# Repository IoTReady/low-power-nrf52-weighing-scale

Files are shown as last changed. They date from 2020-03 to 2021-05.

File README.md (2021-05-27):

# Smart Weighing Scale  

This project describes a Smart Weighing Scale with low current consumption, and hence a long battery backup.

One of the biggest problems with the use of weighing scales in flexible retail or industrial applications is the need to provide a source of power to a scale. This causes problems such as safety hazards with a corded scale, inflexibility of placement since the location of power sources limits where the scale can be placed, and finally the inability to function when there is a power interruption. This design eliminates these disadvanteges.

## Firmware
After cloning or downloading this repo find the firmware documentation here "weighing_scale_nrf/firmware/bootloader/documentation/index.html".

## Circuit

### Power Supply
The nrf Based Weighing Scale operates on 3.3V, and is powered by a 3.7V Li-ion battery.
We use a p-MOSFET(IRLML6401) for reverse polarity protection, and a LDO(Low Drop Out) Regulator(TPS7A0233PDBV) to get a stable 3.3V output supply.

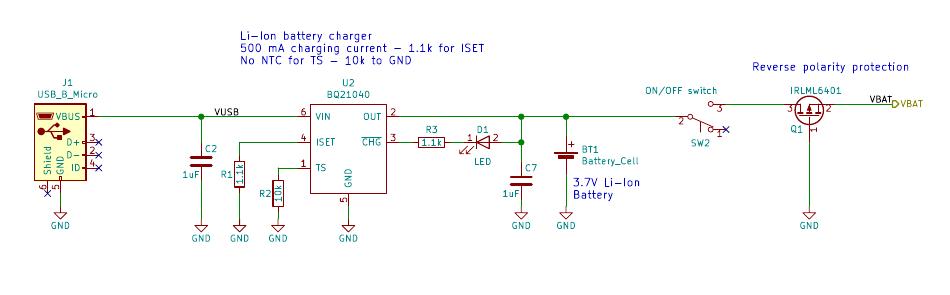
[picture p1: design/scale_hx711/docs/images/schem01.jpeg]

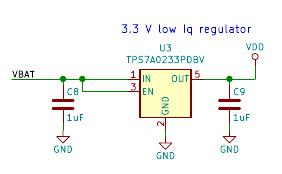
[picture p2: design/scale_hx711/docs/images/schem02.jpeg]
battery


### Battery Charging
We use a Li-ion/Li-polymer linear battery charger IC(BQ21040) for charging the battery via a micro-USB outlet. The led indicator stops glowing when the battery is fully charged.

### nRF Module
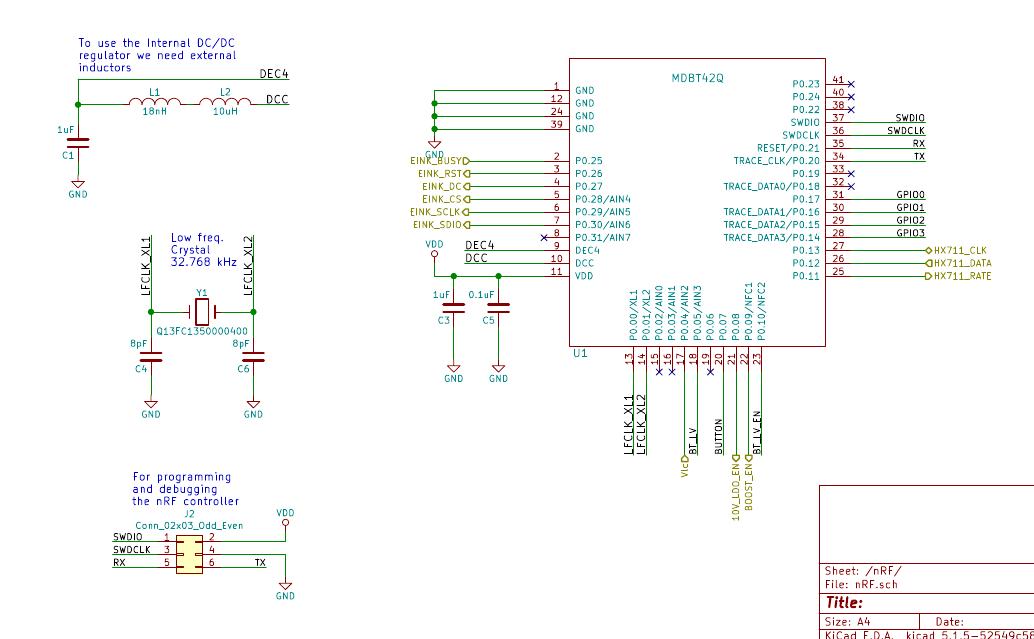
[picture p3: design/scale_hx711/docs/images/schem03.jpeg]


We are using the MDBT42Q nRF52840 based module as our main MCU and BLE module. It is a very low current consuming and high performance module.
It needs a 3.3V power supply, and we are using its internal DC/DC regulator which is set by connecting a 10uH and 18nH inductor at DCC and DEC4 pins as shown here. We also use an external 32.768 kHz external crystal. For programming this module we need a Segger JLink Debugger, which is available as a separate device or one could use an on-board debugger from any of the Nordic Dev-boards like PCA400, etc...
We kept a few GPIOs out for future use or if need to integrate anything else with the weighing scale.

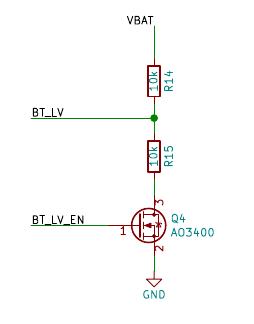
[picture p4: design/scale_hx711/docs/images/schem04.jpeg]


To measure the battery level we use this voltage divider circuit and measure it use the on board ADC pins.

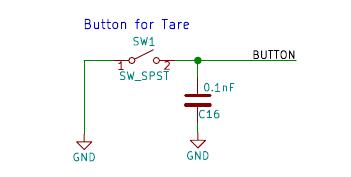
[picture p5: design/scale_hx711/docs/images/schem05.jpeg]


Tare Button is a push button for using the tare functionality. It basically resets the displayed weight on scale back to zero. The Tare button can also be used to measure multiple items in the same container. Simply add you first item, note the weight, press Tare and you are ready to weigh your next item.

### ADC Circuit: HX711
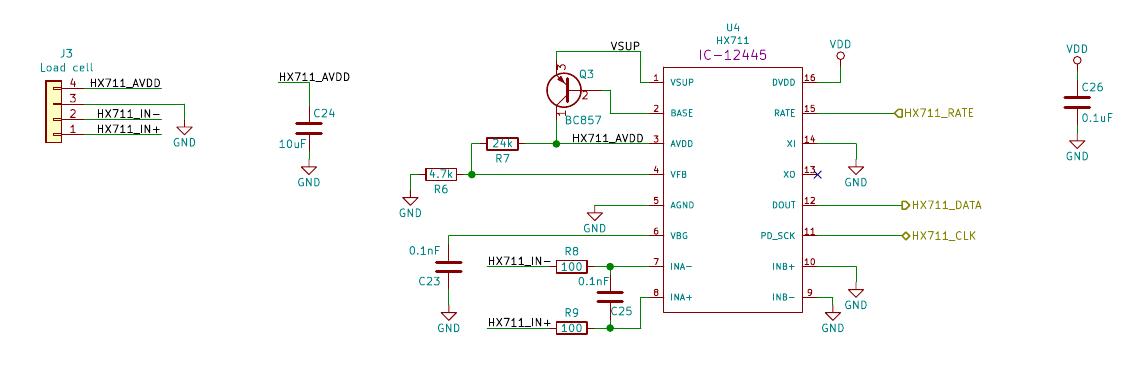
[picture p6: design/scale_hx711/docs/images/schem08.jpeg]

For measuring the weighing scale we use a Load Cell which gives an anlog output, as the weight changes. For high accuracy we use HX711 24-bit ADC chip, which is designed specifically for industrial weighing scales and other industrial control applications.

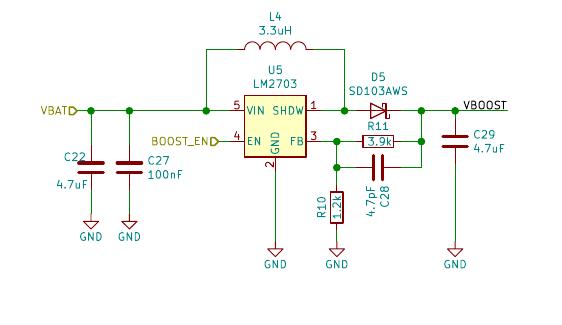
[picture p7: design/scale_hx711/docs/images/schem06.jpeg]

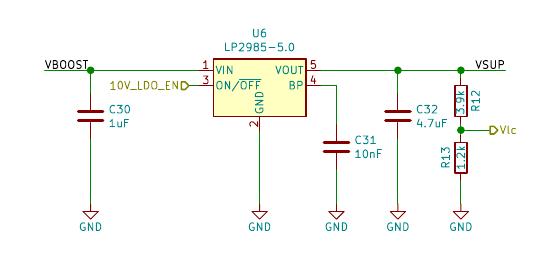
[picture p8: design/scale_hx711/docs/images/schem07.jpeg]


To power the HX711 we need a 5V supply, so we use a Boost regulator(LM2703) to step-up the 3.7V from the battery supply and use an LDO(LP2985-5.0) to get a stable noise free 5V supply for HX711.

The data from the Load Cell is received via four pins HX711_IN+, HX711_IN-, HX711_AVDD and GND. This data is processed by the ADC chip and an output is send via serial interface to the nRF module. We can control the output data rate as either 10Hz or 80Hz by controlling the HX711_RATE pin state.
There is no programming needed for the internal registers. All controls to the HX711 are through the pins.

### E-Ink Display
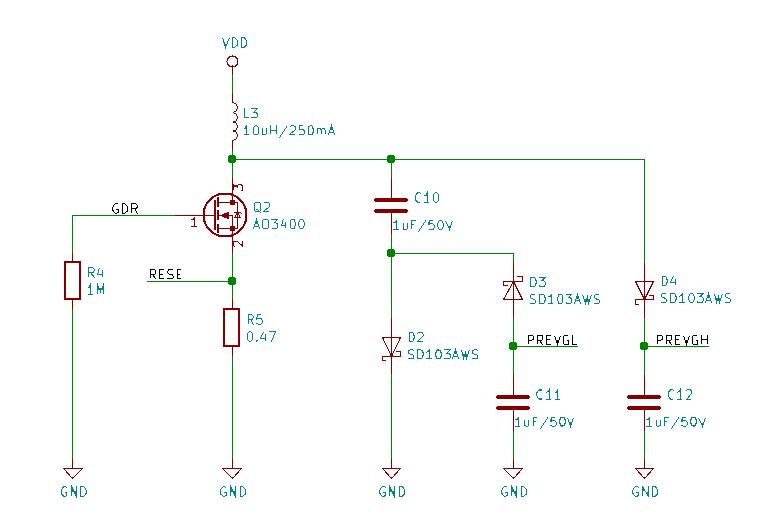
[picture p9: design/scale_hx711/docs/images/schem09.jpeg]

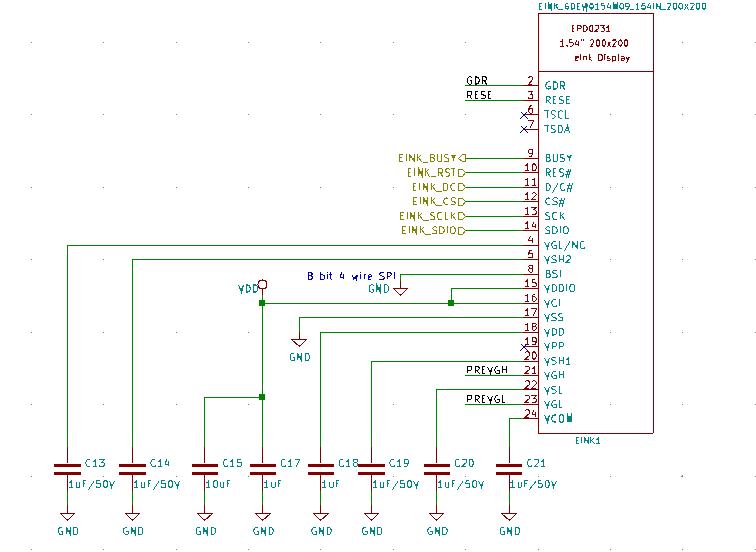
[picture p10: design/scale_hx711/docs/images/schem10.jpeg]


We decided to go with an E-Ink display as it is very low power consuming, reflection resistant, and was useful for the application we were targeting.
This is a 1.54" 200x200 pixel [E-Ink display](https://www.e-paper-display.com/products_detail/productId=513.html) from Good Display.

## PCB
This is what the final PCB design looks like:
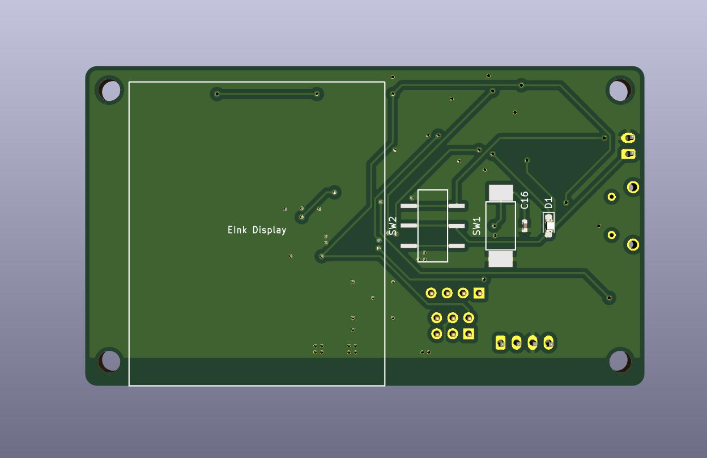
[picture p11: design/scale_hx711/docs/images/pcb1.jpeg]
front_pcb

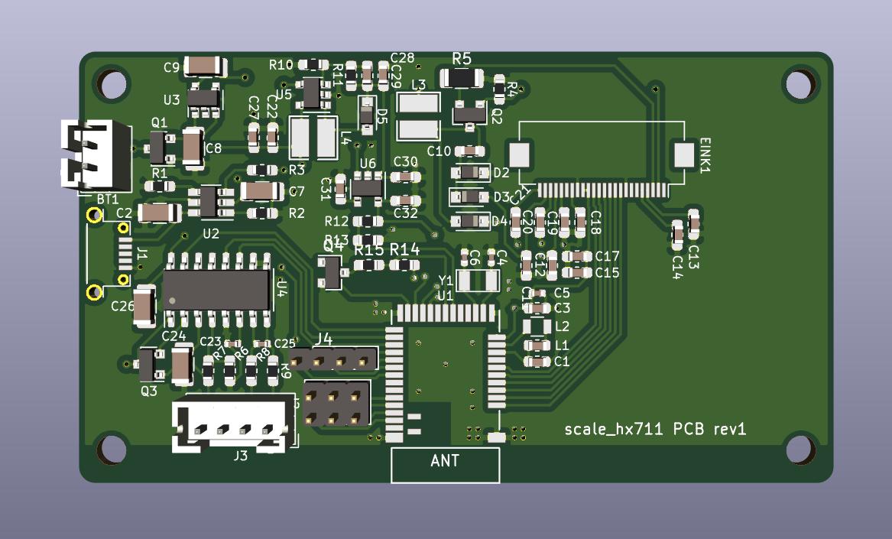
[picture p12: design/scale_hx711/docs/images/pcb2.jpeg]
back_pcb

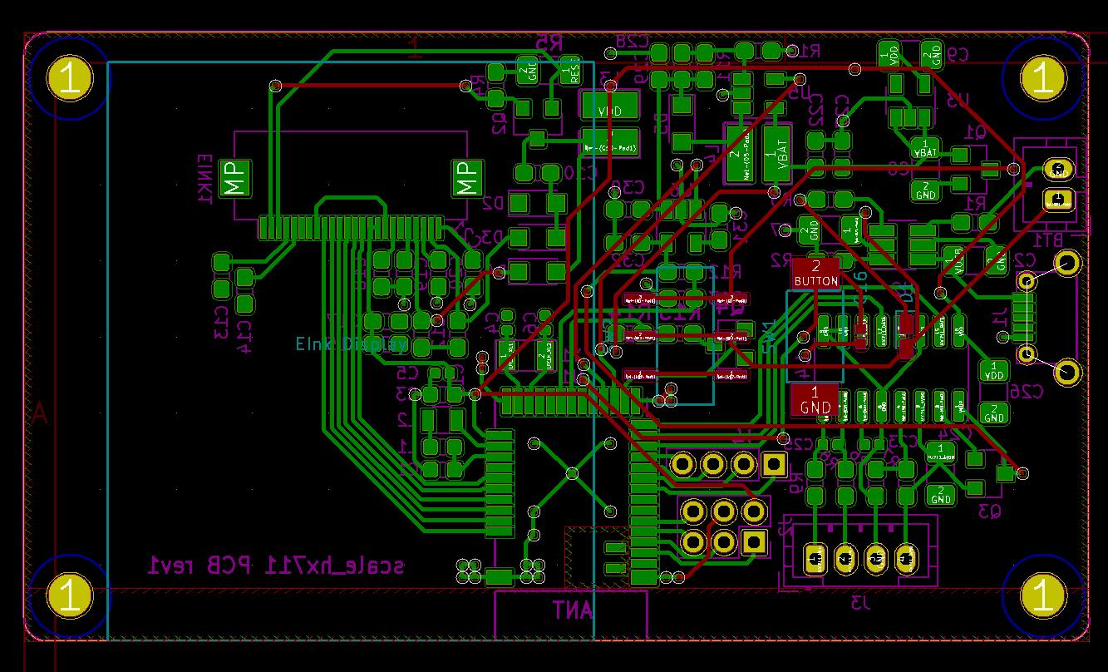
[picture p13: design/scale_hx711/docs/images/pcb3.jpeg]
gerber_pcb


## Hardware Builds

Hardware design files are available in the "design" sub-folder

We tried 3 different designs for the weighing scale project and settled with the "HX711" based design as our final.

So you will find the final design explained on the main page.

The other two designs of "LPV821" and "LTC6915" based weighing scales are also fully functional, one may have to play around with the adc functions in the firmware though.

## Software Builds

One can find the main application with all library files(for e-ink display, and weighing scale) in the "Application" folder.

To setup the Nordic SDK and bootloader files follow the links in "Bootloader" folder. Also, the "documentation" folder has some good technical data.

To make changes in the firmware go to "weighing_scale_nrf/firmware/application/w_scale_all/" and make necessary changes.

To build the output files, go to the same location and use this command to generate final output files(.hex):
```
make release
```

Then use the following to flash and debug the firmware:
```
make upload
```

This is a custom makefile, so make sure all Debugger setings are proper. Like, make sure the Debugge name and Serial Number are correct.

These can be set in this [makefile](https://github.com/IoTReady/weighing_scale_nrf/blob/master/firmware/application/w_scale_all/Makefile).

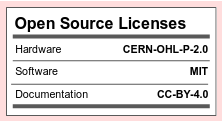
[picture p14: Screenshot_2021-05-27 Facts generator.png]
opensource license


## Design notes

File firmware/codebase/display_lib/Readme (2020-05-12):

This driver gives an abstraction layer for multiple e-paper displays. But,
functionalities provided by this driver will be limited to print text, and 
rectangles.

1. Number of lines calculations. 
Number of pixels per line = (Height of selected font +
                                    Before each line 4 empty pixels)

Max number of lines = (total pixels / no of pixels per line)

2. Number of characters in line = (total pixel / Width of selected font).

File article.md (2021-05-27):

# Building a low power, smart weighing scale

### How did we get into this?

Online grocery shopping is booming. We were approached by a new startup to help them build a tracking infrastructure. A key componet of this infrastructre was a weighing station that could be combined with a bar-code printer and a reader to automatically identify, weigh and update information on Stock Keeping Units (SKU's) as they flowed through the grocery processing flow.

Conventional scales have been manufactured for a long time. Its also possible to fairly easily integrate them with scanners and printers. However in this case more was needed:
 
* Identify everything that's weighed on them and be able to update information on the item
* Integrate the item information into the startups workflow management system
* Enable the placement of these devices where needed by the layout of processing stations, and the ability to move them around as required
* Ensure that these devices were capable of handling power interruptions

Keeping all these features in mind we came up with two variants: Weighing Scales with WiFi or BLE.
After further research, development, feild testing and lots of discussions we decided to go ahead with the BLE alternative. It is much more power efficient, cheaper and met all the requirements we were looking for.

### Hardware design and development

For low power, Bluetooth Low Energy (BLE), there is no better option in the market other than Nordic Semiconductor's nRF series. So, based on requirements, availability and price we went with nRF52840 based module "MDBT42Q". One can find all the design files and a more technical documentation in our GitHub repo [here](https://github.com/IoTReady/weighing_scale_nrf).

Basically a weighing scale has a load cell which helps determine the weight of an object put on it. The load-cell signal uses an op-amp circuit to get a improve the signal and an ADC (Analog-to-Digital Converter) to calculate the final weight of the object. We used the ADC on the nRF52840 chip and for the Amplifier circuit we tried three different options:

* LPV821
* LTC6915
* HX711

After further testing and comparison of all three we decided to go with "HX711" circuit. It gave us the most stable results and power consumption was also the least expensive compared to the rest. We are sharing all three designs in our open-source repo, but we only provide more technical data on HX711 circuit for now.

The next requirement was for a display showing weight, battery life and charging status of the device. To keep it low power we tried out E-Ink displays. They met all our expectations on how much less current they draw compared to conventional LED displays. We settled on a 1.54 inch 200x200 pixel [E-Ink Display](https://www.e-paper-display.com/products_detail/productId=513.html) from Good Display.

Here is some data on the power consumption of the device:

Powering the device is simple. Users can install any 3.7V Li-Ion battery, as per their requirement. It can be charged via the micro-USB port on the device.

Finally, we have a Tare Button. It is a push button user can press to define their own zero reference and measure anything with respect to that.

### Connecting to the Internet

As we decided to go with BLE, there was no way for the device to directly connect to the internet. Hence, we developed a small mobile App which functions as a background gateway between the weighing scale and the factory intranet. A user will link to the device with the mobile App once. The device will keep sending all the weight data measured on it over BLE in addition to recording it, which will then be sent to the internet(company database or inventory tracking application) from the smart phone.

This way we record all the data with minimal power consumption by the device.

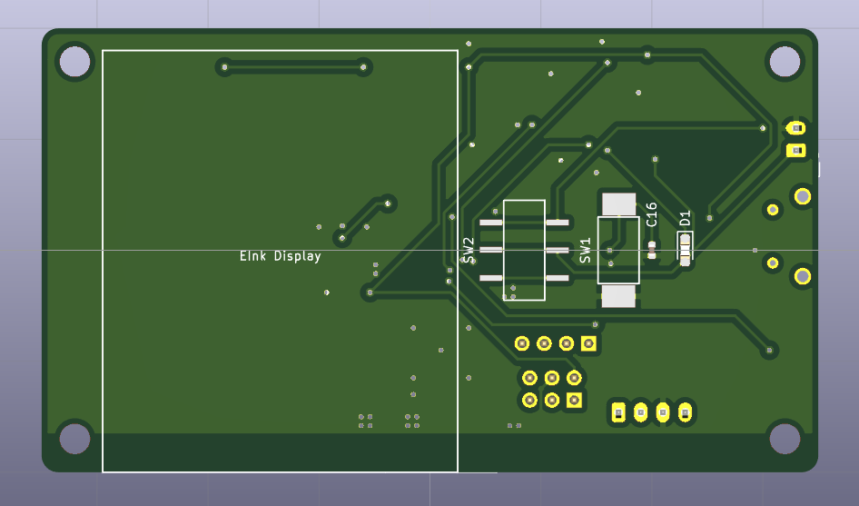
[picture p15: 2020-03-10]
design/scale_hx711/docs/scale_hx711_pcb_1.png

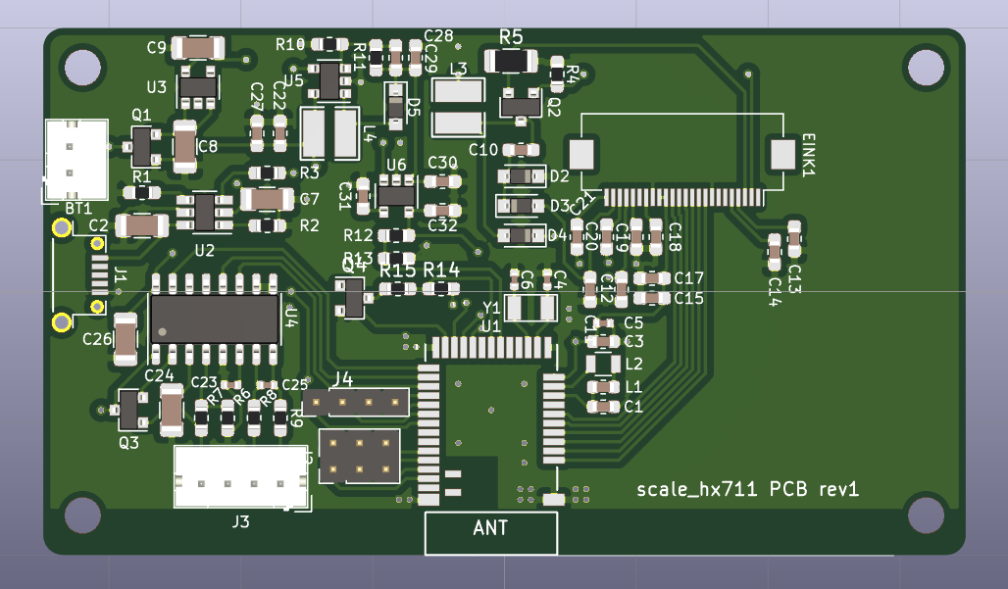
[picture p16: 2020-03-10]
design/scale_hx711/docs/scale_hx711_pcb_2.png

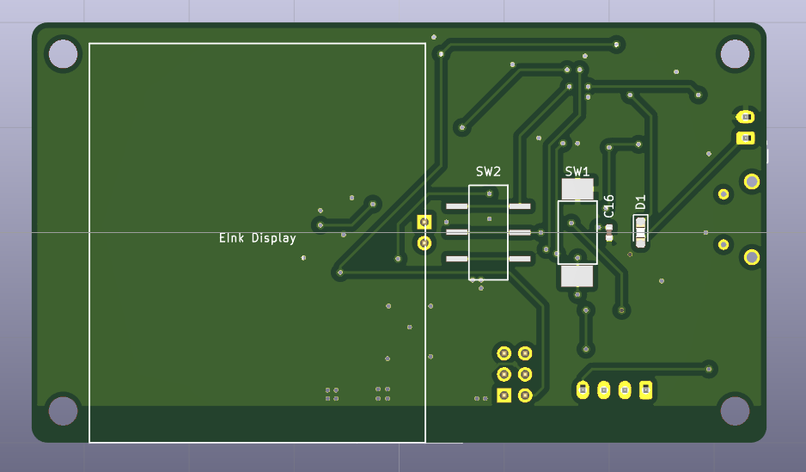
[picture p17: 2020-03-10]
design/scale_ltc6915/docs/scale_ltc6915_pcb_1.png

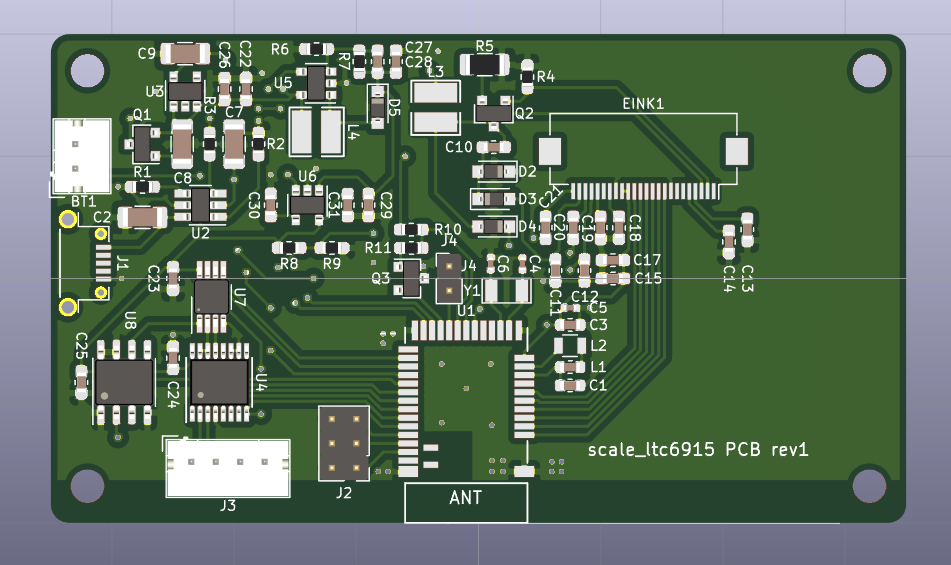
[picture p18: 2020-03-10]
design/scale_ltc6915/docs/scale_ltc6915_pcb_2.png

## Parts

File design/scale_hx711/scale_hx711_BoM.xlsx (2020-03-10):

Source: | /home/shubham/IoTReady/nrf_scale/weighing_scale_nrf/design/scale_hx711/scale_hx711.sch
Date: | Tue Mar 10 15:40:08 2020
Tool: | Eeschema 5.1.5-52549c5~84~ubuntu18.04.1
Component Count: | 79
Ref | Value | Footprint | Datasheet | Manufacturer | Vendor
BT1 | Battery_Cell | Connector_JST:JST_PH_B2B-PH-K_1x02_P2.00mm_Vertical
C1 | 1uF | sense_fp:C_0603_1608Metric
C2 | 1uF | sense_fp:C_1206_3216Metric
C3 | 1uF | sense_fp:C_0603_1608Metric
C4 | 8pF | sense_fp:C_0402_1005Metric
C5 | 0.1uF | sense_fp:C_0402_1005Metric
C6 | 8pF | sense_fp:C_0402_1005Metric
C7 | 1uF | sense_fp:C_1206_3216Metric
C8 | 1uF | sense_fp:C_1206_3216Metric
C9 | 1uF | sense_fp:C_1206_3216Metric
C10 | 1uF/50V | Capacitor_SMD:C_0603_1608Metric_Pad1.05x0.95mm_HandSolder
C11 | 1uF/50V | Capacitor_SMD:C_0603_1608Metric_Pad1.05x0.95mm_HandSolder
C12 | 1uF/50V | Capacitor_SMD:C_0603_1608Metric_Pad1.05x0.95mm_HandSolder
C13 | 1uF/50V | Capacitor_SMD:C_0603_1608Metric_Pad1.05x0.95mm_HandSolder
C14 | 1uF/50V | Capacitor_SMD:C_0603_1608Metric_Pad1.05x0.95mm_HandSolder
C15 | 10uF | Capacitor_SMD:C_0603_1608Metric_Pad1.05x0.95mm_HandSolder
C16 | 0.1nF | sense_fp:C_0402_1005Metric
C17 | 1uF | Capacitor_SMD:C_0603_1608Metric_Pad1.05x0.95mm_HandSolder
C18 | 1uF | Capacitor_SMD:C_0603_1608Metric_Pad1.05x0.95mm_HandSolder
C19 | 1uF/50V | Capacitor_SMD:C_0603_1608Metric_Pad1.05x0.95mm_HandSolder
C20 | 1uF/50V | Capacitor_SMD:C_0603_1608Metric_Pad1.05x0.95mm_HandSolder
C21 | 1uF/50V | Capacitor_SMD:C_0603_1608Metric_Pad1.05x0.95mm_HandSolder
C22 | 4.7uF | Capacitor_SMD:C_0603_1608Metric_Pad1.05x0.95mm_HandSolder | ~
C23 | 0.1nF | sense_fp:C_0402_1005Metric
C24 | 10uF | sense_fp:C_1206_3216Metric
C25 | 0.1nF | sense_fp:C_0402_1005Metric
C26 | 0.1uF | sense_fp:C_1206_3216Metric
C27 | 100nF | Capacitor_SMD:C_0603_1608Metric_Pad1.05x0.95mm_HandSolder | ~
C28 | 4.7pF | Capacitor_SMD:C_0603_1608Metric_Pad1.05x0.95mm_HandSolder | ~
C29 | 4.7uF | Capacitor_SMD:C_0603_1608Metric_Pad1.05x0.95mm_HandSolder | ~
C30 | 1uF | Capacitor_SMD:C_0603_1608Metric_Pad1.05x0.95mm_HandSolder | ~
C31 | 10nF | Capacitor_SMD:C_0603_1608Metric_Pad1.05x0.95mm_HandSolder | ~
C32 | 4.7uF | Capacitor_SMD:C_0603_1608Metric_Pad1.05x0.95mm_HandSolder | ~
D1 | LED | LED_SMD:LED_0603_1608Metric_Castellated
D2 | SD103AWS | Diode_SMD:D_SOD-323_HandSoldering | ~
D3 | SD103AWS | Diode_SMD:D_SOD-323_HandSoldering | ~
D4 | SD103AWS | Diode_SMD:D_SOD-323_HandSoldering | ~
D5 | SD103AWS | Diode_SMD:D_SOD-323_HandSoldering | ~
EINK1 | EINK_GDEW0154M09_154IN_200X200 | Connector_FFC-FPC:Hirose_FH12-24S-0.5SH_1x24-1MP_P0.50mm_Horizontal
J1 | USB_B_Micro | Footprint_nrf_scale:Micro_usb_connector_4_THT_pads | ~
J2 | Conn_02x03_Odd_Even | Connector_PinHeader_2.00mm:PinHeader_2x03_P2.00mm_Vertical | ~
J3 | Load cell | Connector_JST:JST_PH_B4B-PH-K_1x04_P2.00mm_Vertical
J4 | Conn_01x04 | Connector_PinHeader_2.00mm:PinHeader_1x04_P2.00mm_Vertical | ~
L1 | 18nH | sense_fp:C_0603_1608Metric
L2 | 10uH | sense_fp:L_0805
L3 | 10uH/250mA | Footprint_nrf_scale:L_3.5x3.0mm_CD30D22
L4 | 3.3uH | Footprint_nrf_scale:L_3.5x3.0mm_CD30D22
MK1 | Mounting_Hole | sense_fp:MountingHole_2.7mm_M2.5
MK2 | Mounting_Hole | sense_fp:MountingHole_2.7mm_M2.5
MK3 | Mounting_Hole | sense_fp:MountingHole_2.7mm_M2.5
MK4 | Mounting_Hole | sense_fp:MountingHole_2.7mm_M2.5
Q1 | IRLML6401 | Package_TO_SOT_SMD:SOT-23
Q2 | AO3400 | Package_TO_SOT_SMD:SOT-23
Q3 | BC857 | Package_TO_SOT_SMD:SOT-23 | http://www.fairchildsemi.com/ds/BC/BC557.pdf
Q4 | AO3400 | Package_TO_SOT_SMD:SOT-23
R1 | 1.1k | Resistor_SMD:R_0603_1608Metric_Pad1.05x0.95mm_HandSolder
R2 | 10k | Resistor_SMD:R_0603_1608Metric_Pad1.05x0.95mm_HandSolder
R3 | 1.1k | Resistor_SMD:R_0603_1608Metric_Pad1.05x0.95mm_HandSolder
R4 | 1M | Resistor_SMD:R_0603_1608Metric_Pad1.05x0.95mm_HandSolder
R5 | 0.47 | Resistor_SMD:R_1206_3216Metric
R6 | 4.7k | Resistor_SMD:R_0603_1608Metric_Pad1.05x0.95mm_HandSolder
R7 | 24k | Resistor_SMD:R_0603_1608Metric_Pad1.05x0.95mm_HandSolder
R8 | 100 | Resistor_SMD:R_0603_1608Metric_Pad1.05x0.95mm_HandSolder
R9 | 100 | Resistor_SMD:R_0603_1608Metric_Pad1.05x0.95mm_HandSolder
R10 | 1.2k | Resistor_SMD:R_0603_1608Metric_Pad1.05x0.95mm_HandSolder
R11 | 3.9k | Resistor_SMD:R_0603_1608Metric_Pad1.05x0.95mm_HandSolder
R12 | 3.9k | Resistor_SMD:R_0603_1608Metric_Pad1.05x0.95mm_HandSolder
R13 | 1.2k | Resistor_SMD:R_0603_1608Metric_Pad1.05x0.95mm_HandSolder
R14 | 10k | Resistor_SMD:R_0603_1608Metric_Pad1.05x0.95mm_HandSolder
R15 | 10k | Resistor_SMD:R_0603_1608Metric_Pad1.05x0.95mm_HandSolder
SW1 | SW_SPST | Footprint_nrf_scale:SMD Tactile Switch_3x6x2.5mm
SW2 | ON/OFF switch | Footprint_nrf_scale:Slide Switch SMD 2P2T _6pins
U1 | MDBT42Q | sense_fp:mdbt42Q
U2 | BQ21040 | Package_TO_SOT_SMD:SOT-23-6_Handsoldering | http://www.ti.com/lit/ds/symlink/bq21040.pdf
U3 | TPS7A0233PDBV | Package_TO_SOT_SMD:SOT-23-5 | http://www.ti.com/lit/ds/symlink/tps7a02.pdf
U4 | HX711 | Package_SO:SOIC-16_3.9x9.9mm_P1.27mm
U5 | LM2703 | Package_TO_SOT_SMD:SOT-23-5
U6 | LP2985-5.0 | Package_TO_SOT_SMD:SOT-23-5 | http://www.ti.com/lit/ds/symlink/lp2985.pdf
Y1 | Q13FC1350000400 | sense_fp:Q13FC1350000400_SMD Crystals 32.768KHz

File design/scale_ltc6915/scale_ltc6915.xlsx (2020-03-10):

Source: | /home/shubham/IoTReady/nrf_scale/weighing_scale_nrf/design/scale_ltc6915/scale_ltc6915.sch
Date: | Tue Mar 10 15:40:26 2020
Tool: | Eeschema 5.1.5-52549c5~84~ubuntu18.04.1
Component Count: | 75
Ref | Value | Footprint | Datasheet | Manufacturer | Vendor
BT1 | Battery_Cell | Connector_JST:JST_PH_B2B-PH-K_1x02_P2.00mm_Vertical
C1 | 1uF | sense_fp:C_0603_1608Metric
C2 | 1uF | sense_fp:C_1206_3216Metric
C3 | 1uF | sense_fp:C_0603_1608Metric
C4 | 8pF | sense_fp:C_0402_1005Metric
C5 | 0.1uF | sense_fp:C_0402_1005Metric
C6 | 8pF | sense_fp:C_0402_1005Metric
C7 | 1uF | sense_fp:C_1206_3216Metric
C8 | 1uF | sense_fp:C_1206_3216Metric
C9 | 1uF | sense_fp:C_1206_3216Metric
C10 | 1uF/50V | Capacitor_SMD:C_0603_1608Metric_Pad1.05x0.95mm_HandSolder
C11 | 1uF/50V | Capacitor_SMD:C_0603_1608Metric_Pad1.05x0.95mm_HandSolder
C12 | 1uF/50V | Capacitor_SMD:C_0603_1608Metric_Pad1.05x0.95mm_HandSolder
C13 | 1uF/50V | Capacitor_SMD:C_0603_1608Metric_Pad1.05x0.95mm_HandSolder
C14 | 1uF/50V | Capacitor_SMD:C_0603_1608Metric_Pad1.05x0.95mm_HandSolder
C15 | 10uF | Capacitor_SMD:C_0603_1608Metric_Pad1.05x0.95mm_HandSolder
C16 | 0.1nF | sense_fp:C_0402_1005Metric
C17 | 1uF | Capacitor_SMD:C_0603_1608Metric_Pad1.05x0.95mm_HandSolder
C18 | 1uF | Capacitor_SMD:C_0603_1608Metric_Pad1.05x0.95mm_HandSolder
C19 | 1uF/50V | Capacitor_SMD:C_0603_1608Metric_Pad1.05x0.95mm_HandSolder
C20 | 1uF/50V | Capacitor_SMD:C_0603_1608Metric_Pad1.05x0.95mm_HandSolder
C21 | 1uF/50V | Capacitor_SMD:C_0603_1608Metric_Pad1.05x0.95mm_HandSolder
C22 | 4.7uF | Capacitor_SMD:C_0603_1608Metric_Pad1.05x0.95mm_HandSolder | ~
C23 | 0.1uF | Capacitor_SMD:C_0603_1608Metric_Pad1.05x0.95mm_HandSolder | ~
C24 | 0.1uF | Capacitor_SMD:C_0603_1608Metric_Pad1.05x0.95mm_HandSolder | ~
C25 | 0.1uF | Capacitor_SMD:C_0603_1608Metric_Pad1.05x0.95mm_HandSolder | ~
C26 | 100nF | Capacitor_SMD:C_0603_1608Metric_Pad1.05x0.95mm_HandSolder | ~
C27 | 4.7pF | Capacitor_SMD:C_0603_1608Metric_Pad1.05x0.95mm_HandSolder | ~
C28 | 4.7uF | Capacitor_SMD:C_0603_1608Metric_Pad1.05x0.95mm_HandSolder | ~
C29 | 1uF | Capacitor_SMD:C_0603_1608Metric_Pad1.05x0.95mm_HandSolder | ~
C30 | 10nF | Capacitor_SMD:C_0603_1608Metric_Pad1.05x0.95mm_HandSolder | ~
C31 | 4.7uF | Capacitor_SMD:C_0603_1608Metric_Pad1.05x0.95mm_HandSolder | ~
D1 | LED | LED_SMD:LED_0603_1608Metric_Castellated
D2 | SD103AWS | Diode_SMD:D_SOD-323_HandSoldering | ~
D3 | SD103AWS | Diode_SMD:D_SOD-323_HandSoldering | ~
D4 | SD103AWS | Diode_SMD:D_SOD-323_HandSoldering | ~
D5 | SD103AWS | Diode_SMD:D_SOD-323_HandSoldering | ~
EINK1 | EINK_GDEW0154M09_154IN_200X200 | Connector_FFC-FPC:Hirose_FH12-24S-0.5SH_1x24-1MP_P0.50mm_Horizontal
J1 | USB_B_Micro | Footprint_nrf_scale:Micro_usb_connector_4_THT_pads | ~
J2 | Conn_02x03_Odd_Even | Connector_PinHeader_2.00mm:PinHeader_2x03_P2.00mm_Vertical | ~
J3 | Load cell | Connector_JST:JST_PH_B4B-PH-K_1x04_P2.00mm_Vertical
J4 | Conn_01x04 | Connector_PinHeader_2.00mm:PinHeader_1x02_P2.00mm_Vertical | ~
L1 | 18nH | sense_fp:C_0603_1608Metric
L2 | 10uH | sense_fp:L_0805
L3 | 10uH/250mA | Footprint_nrf_scale:L_3.5x3.0mm_CD30D22
L4 | 3.3uH | Footprint_nrf_scale:L_3.5x3.0mm_CD30D22
MK1 | Mounting_Hole | sense_fp:MountingHole_2.7mm_M2.5
MK2 | Mounting_Hole | sense_fp:MountingHole_2.7mm_M2.5
MK3 | Mounting_Hole | sense_fp:MountingHole_2.7mm_M2.5
MK4 | Mounting_Hole | sense_fp:MountingHole_2.7mm_M2.5
Q1 | IRLML6401 | Package_TO_SOT_SMD:SOT-23
Q2 | AO3400 | Package_TO_SOT_SMD:SOT-23
Q3 | AO3400 | Package_TO_SOT_SMD:SOT-23 | ~
R1 | 1.1k | Resistor_SMD:R_0603_1608Metric_Pad1.05x0.95mm_HandSolder
R2 | 10k | Resistor_SMD:R_0603_1608Metric_Pad1.05x0.95mm_HandSolder
R3 | 1.1k | Resistor_SMD:R_0603_1608Metric_Pad1.05x0.95mm_HandSolder
R4 | 1M | Resistor_SMD:R_0603_1608Metric_Pad1.05x0.95mm_HandSolder
R5 | 0.47 | Resistor_SMD:R_1206_3216Metric
R6 | 1.2k | Resistor_SMD:R_0603_1608Metric_Pad1.05x0.95mm_HandSolder
R7 | 3.9k | Resistor_SMD:R_0603_1608Metric_Pad1.05x0.95mm_HandSolder
R8 | 3.9k | Resistor_SMD:R_0603_1608Metric_Pad1.05x0.95mm_HandSolder
R9 | 1.2k | Resistor_SMD:R_0603_1608Metric_Pad1.05x0.95mm_HandSolder
R10 | 10k | Resistor_SMD:R_0603_1608Metric_Pad1.05x0.95mm_HandSolder
R11 | 10k | Resistor_SMD:R_0603_1608Metric_Pad1.05x0.95mm_HandSolder
SW1 | SW_SPST | Footprint_nrf_scale:SMD Tactile Switch_3x6x2.5mm
SW2 | ON/OFF switch | Footprint_nrf_scale:Slide Switch SMD 2P2T _6pins
U1 | MDBT42Q | sense_fp:mdbt42Q
U2 | BQ21040 | Package_TO_SOT_SMD:SOT-23-6_Handsoldering | http://www.ti.com/lit/ds/symlink/bq21040.pdf
U3 | TPS7A0233PDBV | Package_TO_SOT_SMD:SOT-23-5 | http://www.ti.com/lit/ds/symlink/tps7a02.pdf
U4 | LTC6915 | Package_SO:SSOP-16_3.9x4.9mm_P0.635mm
U5 | LM2703 | Package_TO_SOT_SMD:SOT-23-5
U6 | LP2985-5.0 | Package_TO_SOT_SMD:SOT-23-5 | http://www.ti.com/lit/ds/symlink/lp2985.pdf
U7 | ADS8320E_2K5 | Package_SO:VSSOP-8_3.0x3.0mm_P0.65mm | Texas Instruments
U8 | LM4140CCM-2.5 | Package_SO:SOIC-8_3.9x4.9mm_P1.27mm | NationalSemiconductor
Y1 | Q13FC1350000400 | sense_fp:Q13FC1350000400_SMD Crystals 32.768KHz

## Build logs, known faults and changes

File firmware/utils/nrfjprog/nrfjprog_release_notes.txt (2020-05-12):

Release 9.3.1
Changelog
---------------------------------------
- (Exe)     Added the possibility to combine --eraseall and --qspieraseall option.
- (Exe)     Added the options --qspisectorerase and --qspichiperase for the --program operation.
- (Exe)     Accelerated --program operation when the target was an external memory device connected through QSPI.
- (Exe)     Updated QSPIDefault.ini file with new configuration options.
- (Exe)     Added function --readqspi.
- (Exe)     Updated default values for Frequency, WriteMode and ReadMode in  QSPIDefault.ini.

- (Dll)     Eliminated pop-up for unprotect action introduced in JLinkARM.dll version 6.13a or later for nRF51 devices. The default action is to not unprotect the device.
- (Dll)     Added function NRFJPROG_is_dll_open().
- (Dll)     Added function NRFJPROG_is_rtt_started().
- (Dll)     Added function NRFJPROG_is_qspi_init().
- (Dll)     Removed the 4k limitation on NRFJPROG_qspi_write() and NRFJPROG_qspi_read() functions to speed QSPI operation.
- (Dll)     Expanded qspi_init_params_t to include new parameters.
- (Dll)     Added missing return value INVALID_OPERATION to the documentation for functions NRFJPROG_debug_reset(), NRFJPROG_qspi_init(), NRFJPROG_qspi_uninit(), NRFJPROG_qspi_read(), NRFJPROG_qspi_write(), NRFJPROG_qspi_erase(), NRFJPROG_qspi_custom() for nRF51 devices.
- (Dll)     Added missing return value INVALID_OPERATION to the documentation for function NRFJPROG_read_region_0_size_and_source() for nRF52 devices.
- (Dll)     Optimized functions NRFJPROG_read_debug_port_register() and NRFJPROG_write_debug_port_register() use of the DP.SELECT register.
- (Dll)     Optimized function NRFJPROG_write() for nRF52 devices.
- (Dll)     Made function NRFJPROG_readback_status() more robust for nRF52. If the function was called exactly at the same moment a soft_reset occurred in the device, protection status ALL was returned independently of the actual readback status.
- (Dll)     Solved issue in NRFJPROG_read_debug_port_register(), NRFJPROG_write_debug_port_register(), NRFJPROG_read_access_port_register() and NRFJPROG_write_access_port_register(). Now these functions cannot be called after NRFJPROG_connect_to_device() is called. Note that many functions implicitly call NRFJPROG_connect_to_device().
- (Dll)     Limited the use of NRFJPROG_rtt_stop() operation. It can only be used when NRFJPROG_rtt_start() function has been called.
- (Dll)     Modified NRFJPROG_debug_reset() to perform a the soft reset using the core AIRCR register if we had already established a connection, since NRFJPROG_write_access_port_register() is not available then.

- (Python)  Added is_open(), is_rtt_started() and is_qspi_init() functions to give support to new DLL functions.
- (Python)  Fixed minor bug in Hex.py module when parsing a file. The file parsed was not closed automatically so it was consuming more resources than necessary, and producing warnings if used in unittest module in Python 3.
- (Python)  Fixed bug in Jlink.py module. The default location for the search for JLinkARM.dll in 32-bit Windows Operating System was wrong.
- (Python)  Adapted to match new QSPI configuration options.
- (Python)  Updated default values of QSPI configuration options.

Release 9.2.1
Changelog
---------------------------------------
- (WindowsRelease)    Updated Segger JLinkARM installer to JLink_Windows_V612a.exe

Release 9.2.0
Changelog
---------------------------------------
- (Exe)     Clarified help for --readuicr, --readcode and --readram, --recover, --program and --ramwr operations.
- (Exe)     Added support for NRF52840 device.
- (Exe)     Modified options --program, --verify, --erasepage, --memrd and --memwr to work with external memories through the QSPI peripheral.
- (Exe)     Added --qspiini and --qspieraseall to work with external memories through the QSPI peripheral.
- (Exe)     Repurposed error UnavailableOperationInFamilyError for operations also unavailable in your device.

- (Dll)     Added support for NRF52_FP2_ENGA device.
- (Dll)     Fixed minor bug in NRFJPROG_readback_status() function. Values outside the valid range were accepted but the function did nothing. INVALID_PARAMETER error is returned instead. 
- (Dll)     Adapted function NRFJPROG_disable_bprot() for nRF52840 device. BPROT is not available in that device and ACL should be used instead. New return code for NRFJPROG_recover() and NRFJPROG_disable_bprot() functions due to this change.
- (Dll)     NRFJPROG_read_device_version() function will now update the output parameter to NRF5x_FPx_FUTURE if a newer unknown version of a known device is found. Only applicable for NRF52 devices or later. See DllCommonDefinitions.h for possible values of x.
- (Dll)     NRFJPROG_read_device_version() function will now update the output parameter version to UNKNOWN if the device is not of the family used. WRONG_FAMILY_FOR_DEVICE return error is still being returned.
- (Dll)     Modified behaviour for unknown revisions of known devices. If a newer unknown revision of a known device is found, the dll will behave as the latest known revision of that device. Only applicable for NRF52 devices or later.
- (Dll)     Added functions NRFJPROG_qspi_init(), NRFJPROG_qspi_uninit(), NRFJPROG_qspi_read(), NRFJPROG_qspi_write(), NRFJPROG_qspi_erase() and NRFJPROG_qspi_custom().
- (Dll)     Deprecated NRFJPROG_is_ram_powered() function.
- (Dll)     Documented a missing side-effect and return value for NRFJPROG_is_ram_powered() function for nRF51 devices.
- (Dll)     Added functions NRFJPROG_read_ram_sections_count(), NRFJPROG_read_ram_sections_size() and NRFJPROG_read_ram_sections_power_status() to substitute deprecated function.

- (Python)  Added support for 64bit on Windows. Pynrfjprog will now work with 64 bits python.
- (Python)  Added support for NRF52_FP2_ENGA device.
- (Python)  Added new devices NRF52_FP1_FUTURE and NRF52_FP2_FUTURE to DeviceVersion enum.
- (Python)  Added support for loading nrfjprog DLLs by name if the nrfjprog DLLs cannot be located in the default pynrfjprog installation directory.
- (Python)  Added qspi_init(), qspi_uninit(), qspi_read(), qspi_write() qspi_erase() and qspi_custom() to give support for new DLL functions.
- (Python)  Added read_ram_sections_count(), read_ram_sections_size() and read_ram_sections_power_status() to give support for new DLL functions.

Release 9.1.0
Changelog
---------------------------------------
- (Exe)     Provided option --jdll to manually select desired Segger's JLinkARM dll instead of automatically search for latest installed Segger's JLinkARM dll.

- (Dll)     Added NRFJPROG_read_connected_emu_fwstr() function to read emulator firmware string.

- (Python)  Added support for NRFJPROG_read_connected_emu_fwstr().

Release 9.0.0
Changelog
---------------------------------------
- (WindowsRelease)    Updated Segger JLinkARM installer to Setup_JLinkV512g.exe

- (Exe)     Provided better feedback when --eraseuicr operation fails due to missing pre-programmed ANT softdevice for nRF51.
- (Exe)     Corrected minor bug in opening hex file in --program. If the user has no read permission on the file, a new error NoReadPermissionError is thrown, instead of InvalidHexFileError.
- (Exe)     Modified error NrfjprogIniFormatError. That error was used in very different situations. Now possible errors of ini file parsing are NrfjprogIniCannotBeOpenedError, NrfjprogIniFamilyMissingError and NrfjprogIniClockspeedMissingError.
- (Exe)     Modified parsing of nrfjprog.ini files to be performed only if needed.
- (Exe)     Fixed --recover for nRF52 devices. In rare circumstances, --recover failed and did not unportect the device.

- (Dll)     Added NRFJPROG_read_connected_emu_snr() function.
- (Dll)     Fixed error in NRFJPPROG_recover() function. In rare circumstances, NRFJPPROG_recover() failed and did not unportect the device.
- (Dll)     Documented a missing side-effect of NRFJPROG_recover() function for nRF51 devices. All peripherals will be reset.
- (Dll)     Documented a missing side-effect of NRFJPROG_recover() function for nRF52 devices. If the device was readback protected, the RAM will be erased.
- (Dll)     Added a side-effect to NRFJPROG_recover() function. Register RESETREAS in POWER peripheral will be cleared after the operation.
- (Dll)     Added new possible error return in NRFJPROG_erase_uicr() NRFJPROG_erase_all functions for nRF51. Returning NOT_AVAILABLE_BECAUSE_MPU_CONFIG instead of NOT_AVAILABLE_BECAUSE_PROTECTION error.

- (Python)  Moved MultiAPI class to its own module MultiAPI.py.
- (Python)  Added read_connected_emu_snr() function.
- (Python)  Added optional parameter encoding to rtt_read and rtt_write data. Different encodings can be now used to write and interpret the read data from the device. If None, they will not be interpreted.
- (Python)  Corrected error in log functionality. Previous release changes set the default error output to sys.stdout.
- (Python)  Corrected error in log functionality. Previous release had b'' in the log in Python 3.
- (Python)  Added new possible error NOT_AVAILABLE_BECAUSE_MPU_CONFIG to API.NrfjprogdllErr enums.

Release 8.5.0
Changelog
---------------------------------------
- (WindowsRelease)    Updated Segger JLinkARM installer to Setup_JLinkV512f.exe

- (Exe)     Added the possibility to perform --reset as part of the --program operations.
- (Exe)     Added the possibility to perform --debugreset as part of the --program operations.
- (Exe)     Corrected bug in getting correct SEGGER .dylib version in OS X.

- (Dll)     Corrected bug in NRFJPROG_rtt_start() function for NRF51_XLR3P devices. If the RTT buffer address was in the range 0x20004000-0x20008000, the RTT buffer was never discovered.
- (Dll)     Corrected bug in NRFJPROG_rtt_start() function for NRF52_FP1_ENGA devices. If the RTT buffer address was in the range 0x08000000-0x08008000, the RTT buffer was never discovered.
- (Dll)     Added WRONG_FAMILY_FOR_DEVICE as a possible return value for NRFJPROG_rtt_start() function.

- (Python)  Fixed problem in JLink.py. In Linux Segger release V5.10s or latter, the 64-bit and 32-bit shared objects were both included. The wrong one was selected.
- (Python)  Fixed problem in JLink.py. If Segger installation folder does not exist, return None.
- (Python)  Corrected bug in JLink.py getting correct SEGGER .dylib version in OS X.
- (Python)  Added optional log, log_str and log_file_path parameters to API and MultiAPI class's constructors so user can define logging, a log string to precede debug output and/or a file where all debug output should be redirected.
- (Python)  Removed log_str_cb parameter from MultiAPI class's constructor as it was not functional.
- (Python)  Performed a general refactor of the code with no effect on API or performance.
- (Python)  Allow arrays and other containers to be passed to write() instead of just lists and tuples.
- (Python)  Deprecated Hex.py. We recommend using intelhex for parsing hex files. Hex.py is still available for compatibility with old scripts.

Release 8.4.0
Changelog
---------------------------------------
- (WindowsRelease)    Added nrf51_nrfjprogdll.h and nrf52_nrfjprogdll.h headers to the release.

- (OSXRelease)        Added nrf51_nrfjprogdll.h and nrf52_nrfjprogdll.h headers to the release.

- (LinuxRelease)      Added nrf51_nrfjprogdll.h and nrf52_nrfjprogdll.h headers to the release.

- (Exe)     Added --pinresetenable option.

- (Dll)     Eliminated undesired side effect in NRFJPROG_go() function. If the device CPU was not halted when NRFJPROG_go() function was called, the device CPU was temporarily halted and restarted again.
- (Dll)     Corrected error in NRFJPROG_open_dll() function when detecting that the JLinkARM.dll version was too old.
- (Dll)     Required device connection for function NRFJPROG_read_device_version() for nRF52 devices. It will therefore fail if the device is readback protected.
- (Dll)     Modified reset performed during NRFJPROG_readback_protect() from NRFJPROG_sys_reset() to NRFJPROG_debug_reset() to avoid problems when just protecting for nRF52 devices.
- (Dll)     Fixed wrong return in NRFJPROG_readback_protect() function for nRF52 Engineering Sample A devices. Now it correctly fails with INVALID_DEVICE_FOR_OPERATION.
- (Dll)     Disable trace resources when performing a NRFJPROG_readback_protect() to avoid current consumption until a hard reset was performed for nRF52 devices.
- (Dll)     Eliminated the check for correct family in NRFJPROG_readback_protect(), NRFJPROG_recover(), NRFJPROG_disable_bprot(), NRFJPROG_erase_all(), NRFJPROG_erase_page(), NRFJPROG_erase_uicr(), NRFJPROG_write_u32(), NRFJPROG_write(), NRFJPROG_read_u32(), NRFJPROG_read(), NRFJPROG_is_ram_powered(), NRFJPROG_power_ram_all() and NRFJPROG_unpower_ram_section() functions for nRF52 devices.
- (Dll)     Eliminated the check for correct family in NRFJPROG_readback_protect(), NRFJPROG_readback_status(), NRFJPROG_read_region_0_size_andsource(), NRFJPROG_disable_bprot(), NRFJPROG_erase_all(), NRFJPROG_erase_page(), NRFJPROG_erase_uicr(), NRFJPROG_write_u32(), NRFJPROG_write(), NRFJPROG_read_u32(), NRFJPROG_read(), NRFJPROG_power_ram_all() and NRFJPROG_unpower_ram_section() functions for nRF51 devices.

- (Python)  Added nrf51_nrfjprogdll.h and nrf52_nrfjprogdll.h headers to the docs folder.
- (Python)  Updated setup.py with OSX information.

Release 8.3.0
Changelog
---------------------------------------
- (Exe)     Fixed bug in parsing a hex file in --program and --verify when hex file contained a line with less than 4 bytes of data.

- (Dll)     Improved NRFJPROG_write() function to handle non multiple of 4 write lengths.
- (Dll)     Added NRFJPROG_rtt_is_control_block_found() function.
- (Dll)     Fixed bug in NRFJPROG_rtt_stop(). If the sequence NRFJPROG_rtt_start() -> NRFJPROG_rtt_stop() -> NRFJPROG_rtt_start() was executed, the second
            NRFJPROG_rtt_start () only searched for the RTT Control Block in the address the block was found in the first NRFJPROG_rtt_start().  The side-effect
            of this fix is that if you were performing NRFJPROG_rtt_start() -> NRFJPROG_rtt_stop() -> NRFJPROG_rtt_start() with the RTT Control Block in the
            same address, the second NRFJPROG_rtt_start() will take longer than before.
- (Dll)     Modifed the way devices are identified.

- (Python)  Change made in API.py to remove Python 3 warning of deprecated os function call.
- (Python)  Added rtt_is_control_block_found() function.

Release 8.2.0
Changelog
---------------------------------------
- (WindowsRelease)    Updated Segger JLinkARM installer to Setup_JLinkV510i.exe

- (OSXRelease)  Added OSX release in nRF5x-Command-Line-Tools_8_2_0_OSX.tar

- (Exe)     Ported to OSX.
- (Exe)     Fixed bug in --recover for NRF52 devices.
- (Exe)     Fixed bug in --reset and --run. The CPU core was halted some ms after the operation took effect and restarted restart later.

- (Dll)     Ported to OSX.
- (Dll)     Fixed bug in NRFJPROG_recover() function for NRF52 devices.
- (Dll)     Corrected header file documentation for function NRFJPROG_disconnect_from_emulator(). One possible return value for nRF52 devices was missing.

- (Python)  Ported to OSX.
- (Python)  Added object MultiAPI to be able to debug more than one device at the same time.
- (Python)  Fixed bug in get_latest_dll() in file JLink.py. In Python 3 this function failed because you cannot compare an int to a string.

Release 8.1.0
Changelog
---------------------------------------
- (Exe)     Eliminated sys_reset when performing --erasepage operation.
- (Exe)     Fixed small bug in --memrd. If the device was an nRF52 EngA version, the checking of the power state of the RAM was wrong. See Errata-65 for nRF52 devices for details.
- (Exe)     Fixed small bug in --memwr. If the device was an nRF52 EngA version, the checking of the power state of the RAM was wrong. See Errata-65 for nRF52 devices for details.
- (Exe)     Fixed small bug in --ramwr. If the device was an nRF52 EngA version, the checking of the power state of the RAM was wrong. See Errata-65 for nRF52 devices for details.

- (Dll)     Added NRFJPROG_step() function.
- (Dll)     Updated commentary in NRFJPROG_unpower_ram_section() function. Referenced Errata-65 for nRF52 devices EngA version.
- (Dll)     Updated commentary in NRFJPROG_is_ram_powered() function. Referenced Errata-65 for nRF52 devices EngA version.

- (Python)  Added step() function.
- (Python)  Fixed mix of tabs and spaces in program_multiple_hex_files.py.

Release 8.0.0
Changelog
---------------------------------------
- (WindowsRelease)    Renamed installer to nRF5x-Command-Line-Tools_x_x_x_Installer.exe.
- (WindowsRelease)    Added nrfjprog.h to release.
- (WindowsRelease)    Updated installer to Setup_JLinkV510d.exe

- (LinuxRelease)    Added nrfjprog.h to release.
- (LinuxRelease)    Changed structure of release.
- (LinuxRelease)    Included 32-bit versions of tools.

- (Exe)     Fixed bug in --sectoranduicrerase option for NRF51.
- (Exe)     Changed how shared libraries are found on Linux.
- (Exe)     Fixed minor bug in Segger JLinkARM dll version when minor version was 0x in --version.
- (Exe)     Added 32-bit support for Linux.
- (Exe)     Updated help text for clockspeed option.
- (Exe)     Added --debugreset option.
- (exe)     Improved detection of error in --family parameter.

- (Dll)     Fixed bug in enum_emu_snr() and connect_to_emu_without_snr(). Could sometimes cause a freeze of the Segger emulator.
- (Dll)     Sped up read_u32() and write_u32() functions.
- (Dll)     Added functions for RTT.
- (Dll)     Renamed exported functions to avoid collision with a C++ library in OSX.
- (Dll)     Renamed device NRF52_FP1_MPW3 to NRF52_FP1_ENGA and NRF52_FP1 to NRF52_FP1_ENGB.
- (Dll)     Added device NRF52_FP1.
- (Dll)     Added 32-bit support for Linux.
- (Dll)     Changed JLINKARM_SWD_MAX_SPEED_KHZ from 12000 to 50000.
- (Dll)     Change all functions calls that are with connection to the device to return a new error if the device is not of the family used in open_dll() function.

- (Python)  Added functions for RTT.
- (Python)  Adapted to name change in exported functions.
- (Python)  Changed location of dll in installation.
- (Python)  Renamed DeviceVersion enumerations NRF52_FP1_MPW3 to NRF52_FP1_ENGA and NRF52_FP1 to NRF52_FP1_ENGB.
- (Python)  Added DeviceVersion enumeration NRF52_FP1.
- (Python)  Added 32-bit support for Linux.
- (Python)  Added debug_reset function.
- (Python)  Added new error from the dll.
- (Python)  Updated examples to changes from the dll.
- (Python)  In Windows, JLink.py now finds most recent JLinkARM.dll in default SEGGER directory when folders other than Jlink software packs are present.

Release 7.7.0
Changelog
---------------------------------------
- (Exe)     Ported to linux.
- (Exe)     Clockspeed default is now read from the nrfjprog.ini file.

- (Dll)     Ported to linux.
- (Dll)     Added fix for write function for FPGA problem.

- (Python)  Ported to linux.
- (Python)  Changed import of nrfjprog dll from ordinal linking to symbolic linking.

Release 7.6.0
Changelog
---------------------------------------
- (Bundle)  Updated installer to Setup_JLinkV502.exe

- (Exe)     Added --sectoranduicrerase for --program operations and NRF52.
- (Exe)     Added --verify as a stand alone operation.
- (Exe)     Improved the --help output.

- (Dll)     Updated minimum JLinkARM.dll version to 5.02.
- (Dll)     Eliminated disabling of Supply Power to device in connexion to the emulator.
- (Dll)     Cleared the header commentaries.

- (Python)  Added new example for pynrfjprog (program_multiple_hex_files.py).
- (Python)  Updated hex files used by program_hex.py to work on development boards.
- (Python)  Cleared the commentaries.

Release 7.5.2
Changelog
---------------------------------------
- (Exe)     Changed functionality of --program --sectorerase with respects to UICR.

- (Dll)     Fixed problem in dll closing.

Release 7.5.1
Changelog
---------------------------------------
- (Exe)     Fixed problem with programming files whose length of segments were not multiple of 4.
- (Exe)     Eliminated --clean option in --program.
- (Exe)     Added --chiperase and --sectorerase in --program.

- (Dll)     Added disabling of trace resources when disconnecting.
- (Dll)     Improved speed.
- (Dll)     Corrected problems in recover() for nrf52.
- (Dll)     Corrected problems in pin_reset() for nrf52.
- (Dll)     Workaround for Errata 44 "Read flash after erase is unpredictable" added for nrf52.

- (Python)  Added BSD license to project.
- (Python)  Fixed api for function disconnect_from_emu().
- (Python)  Updated Hex.py with extended segment address.
- (Python)  Added comments and new example.

Release 7.5.0
Changelog
---------------------------------------
- (Bundle)  Updated installer to Setup_JLinkV498c.exe. Corrects a bug in OBD for our device programming.

- (Msi)     Pynrfjprog is no longer copied with nrfjprog installation. Own installation will be provided.
- (Msi)     Solved problem of installing into older versions.
- (Msi)     Added documentation folder for the release notes.
- (Msi)     Added header folder for the dll header files.

- (Exe)     Modified default family, it is now taken from nrfjprog.ini file.
- (Exe)     Modified --family and --rbp to accept the parameters in any combination of lower and upper case.
- (Exe)     Added --quiet option.
- (Exe)     Eliminated change introduced in 7.3.2 to avoid problems with our OBD. Program is fast again.
- (Exe)     Fixed bug in --eraseuicr. It could not be executed.
- (Exe)     Made return codes for nrfjprog POSIX compliant.
- (Exe)     Added --erasepage function.
- (Exe)     Eliminated --erasecode function.
- (Exe)     Enforcing that PC address in --run must be thumb mode.
- (Exe)     It is now possible to make unaligned reads. Default width depends on the alignment.
- (Exe)     Fixed bug in --ficrwr. It will not masserase if it is not necessary.
- (Exe)     Modified --memwr so it fails if the area to write is not erased.

- (Dll)     Renamed power_ram() function to power_ram_all().
- (Dll)     Added unpower_ram_section() function.
- (Dll)     Modified read() function so addresses no longer need to be word aligned.
- (Dll)     Corrected bug in readback_protect for XLR and XLR2 devices.

- (Python)  Adapted to dll api changes.
- (Python)  Eliminated Enums.py. Used library available in Python 2.7.9 enum34. Installed automatically by the egg.
- (Python)  Eliminated unnecessary check for length 0 in read(). The dll already takes care of that case.
- (Python)  Added header files to the egg.
- (Python)  Added examples to egg.
- (Python)  Moved headers to own folder.

Release 7.4.0
Changelog
---------------------------------------
- (Bundle)  Updated installer to Setup_JLinkV498b.exe
- (Exe)     Corrected bug introduced in 7.2.2 release. -d will reset the device and run.
- (Exe)     Eliminated --disablepinreset and --enablepinreset. The functionality is not going to be present in the ASIC.
- (Dll)     Updated minimum JLinkARM.dll version to 4.98.
- (Dll)     Extending waiting time for NVMC operations hundredfold. Some operations were failing.
- (Dll)     Eliminated disable_pin_reset() and enable_pin_reset(). The functionality is not going to be present in the ASIC.
- (Dll)     Eliminated read_debug_register(). Added read_debug_port_register() and read_access_port_register() instead.
- (Dll)     Eliminated write_debug_register(). Added write_debug_port_register() and write_access_port_register() instead.
- (Python)  Adapted to dll api changes.
- (Python)  Added JLink.py that helps in finding the latest dll.
- (Python)  Modified open() function api. Eliminated redundant parameter, since the constructor already receives it.

Release 7.3.2
Changelog
---------------------------------------
- (Exe)     Fixed bug in --program for NRF51 introduced in 7.3.1
- (Exe)     Modified --program to avoid problems with the OBD debugger in our boards. Side effect is that now program uses more time.

Release 7.3.1
Changelog
---------------------------------------
- (Exe)     Adapted for NRF52_FP1.
- (Dll)     Eliminated all use of pin_reset() for NRF52. It might not be enabled in the UICR.
- (Dll)     Added NRF52_FP1 type device.
- (Python)  Make a proper package installation for pynrfjprog.

Release 7.2.3
Changelog
---------------------------------------
- (Exe)     Corrected bug introduced in 7.2.2 release. -r and -p will reset the device and run. all other operations will not.
- (Python)  Optimized Hex.py to accelerate downloading.

Release 7.2.2
Changelog
---------------------------------------
- (Exe)     Corrected serious bug. When closing the core was restarted. If there was no code in the device, a hardfault and lockup reset was produced, resetting the device and clearing write operations.

Release 7.2.1
Changelog
---------------------------------------
- (Exe)     Corrected serious bug. When the Dll returned error, the close_dll() function was not called. After several errors the Segger emulator needed to be unpowered since there were too many connexions open to it.
- (Exe)     Corrected minor bug. After erasing an nRF51 device protected by MPU, a reset was not performed, so the device still thought it was protected. A sys_reset is performed after --eraseall and --clean during program.

Release 7.2.0
Changelog
---------------------------------------
- (Exe)     Renamed --rawwr to --ramwr.
- (Dll)     recover() functions now switches on all RAM.
- (Dll)     Segger debugger unpowers the debug port when close_dll() is called.
- (Python)  Added Hex.py to parse hex files to use with API.API.write function.

Release 7.1.0
Changelog
---------------------------------------
- (Exe) Added --clean option to --program. --clean erases all user available flash (including UICR).
- (Exe) RAM is turned on in the --program operation.
- (Exe) Added error and corresponding user feedback for a too old version of JLinkARM.dll used in the machine.
- (Exe) Added warning when --family is not used.
- (Exe) A --memrd, --memwr, --rawwr and --readram will fail if the target RAM is unpowered.
- (Dll) Added function is_ram_powered().
- (Dll) Added function power_ram().
- (Dll) Added function read_debug_register().
- (Dll) Added function write_debug_register().
- (Dll) Function open_dll() returns new error JLINKARM_DLL_TOO_OLD.
- (Dll) Fixed connexion problems under certain circumstances. Device selection was missing.
- (Dll) Fixed caching problems when reading after erase.

Release 7.0.0
Changelog
---------------------------------------
- (Exe) Added support for NRF52. In order to accomplish this, required option --family is added.
- (Exe) Added used JLinkARM.dll version to --version output.
- (Exe) Simplified interface. No longer is possible to concatenate program, erase and reset operations.
- (Exe) Simplified interface. Eliminated all options that dealt with SoftDevice: --programs, --recovers, --eraseapp, --erasecr1 and --programapp.
- (Exe) Simplified interface. --program can no longer have two hex files as parameters.
- (Exe) --program does not automatically erase target area. --clean option added to --program to erase all flash (same as --eraseall) before programming.
- (Exe) Eliminated --quiet option.
- (Exe) Eliminated --logids option. Use pipes for the same effect.
- (Exe) Eliminated deprecated option --dso.
- (Exe) Modified --eraseall. Now it erases all user available flash. It will automatically handle SoftDevice programmed at Nordic factory.
- (Exe) Added --erasecode operation.
- (Exe) Eliminated --erasepage operation.
- (Exe) Eliminated --hexuicrinfo operation.
- (Exe) Memory operations do not automatically check result. Added --verify for verification. Eliminated --ramwr since it does not have sense any more.
- (Dll) Published dll interface and python bindings for use by customer.

Release 5.1.3
Changelog
---------------------------------------
- (Micro) Now nrfjprog.dll and nrfjprog.exe versions upgrade together.

Release 5.1.1
Changelog
---------------------------------------
- (Major) Corrected error with --dfu option of --programs.

Release 5.1.0
Changelog
---------------------------------------
- (Dll.Minor) Eliminated all pop-ups.
- (Dll.Micro) Corrected minor error in loading several JLinkARM.dll functions that were not used.
- (Dll.Micro) Added loading of JLinkARM.dll GetHWInfo() function.

Release 5.0.1
Changelog
---------------------------------------
- (EXE.Micro) Corrected bug in new SDV download (SDV.hex does not contain UICR values). Version 5.0.0 is useless for the purpose it was intended.

Release 5.0.0
Changelog
---------------------------------------
- (EXE.Major) Changed to look for the location of the nrfjprog.dll in the local directory of the executable, not in the registry.
- (EXE.Major) Adapted --recovers, --eraseapp,  --eraseall, --eraseuicr, --erasecr1, programapp and --programs to take into account the new SDV Info struct and maybe no protection.
- (EXE.Minor) Eliminated options --clenr0 and --fwid to --programs.
- (EXE.Micro) Added several parameters for the SoftDevice information. Memory buffers now take into account the size of the SDV, not of region 0.
- (EXE.Micro) Cleaned --ids and --logids to prepare for future changes.
- (EXE.Micro) Cleaned the initialization of path strings.
- (EXE.Micro) Corrected the feedback with incompatible arguments in the --help option.
- (EXE.Micro) Corrected the loading of the nrfjprog dll library. It now occurs with LoadLibraryW as it should.
- (DLL.Major) Added new function read_softdevice_info().
- (DLL.Micro) Corrected minor bug in length of the m_jlink_arm_dll_path array.
- (DLL.Micro) Eliminated extra popup window when disabling system off.
- (DLL.Micro) Changed default value for no emulator selected.
- (DLL.Micro) Disabled caching of the flash.

Release 4.0.5
Changelog
---------------------------------------
- (Micro) Adapted to XLR3+ device.
- (Micro) UICR is not read from the device when programming unless the hex file(s) provided have UICR. Speeds programming.

Release 4.0.4
Changelog
---------------------------------------
- (Micro) Optimized the dynamic memory allocation and deallocation.
- (Micro) Optimized the information functions to DeviceInfo.
- (DLL) Made function pin_reset_ignore_pall work for Quark MPW1.

Release 4.0.3
Changelog
---------------------------------------
- (Micro) Eliminated some safety check that was not needed.
- (Micro) Eliminated a deprecated safety check.
- (Micro) For some device FICR and UICR sizes and code page sizes are different. Now really changed everywhere.

Release 4.0.2
Changelog
---------------------------------------
- (Micro) For some device FICR and UICR sizes and code page sizes are different. Changed everywhere.

Release 4.0.1
Changelog
---------------------------------------
- (DLL)   Fixed problem identifying MPW1.
- (DLL)   Added a lot of functionality related to the MPU to the nrf51dll.dll.

Release 4.0.0
Changelog
---------------------------------------
- (DLL)   Adapted to deprecation in SIZERAMBLOCK[i] registers.
- (Major) Added Quark MPW1 as one of the valid devices.
- (Micro) Eliminated several bugs in parsing the page number in --erasepage.
- (Micro) Added some formating to log.log and error.log so we can see the different commands. Command line is also written.
- (Micro) Corrected default values of RAM and Flash size depending on the device.

Release 3.1.1
Changelog
---------------------------------------
- (DLL)   --pinreset makes now a system reset, halts and then pinresets to avoid a problem with emulated system off.
- (Micro) System Reset is perfrom before any erase operations to avoid problems with emulated system off.

Release 3.1.0
Changelog
---------------------------------------
- (DLL)   Added function check_region_access_ignore_protenset.
- (DLL)   Hardcoded protenset to 4kb as is in XLR2, XLR3 and L3.
- (DLL)   Solved problem with download of programs in XLR in certain circumstances. RAM was off after certain resets.
- (Minor) Added --halt option.
- (Minor) Disable protenset during a memory write operation will only happen during a --memwr to flash area.
- (Micro) Added some information to the help of erase and program operations.
- (Micro) Disable protenset during a program operation will only happen if there is a download to flash area.
- (Micro) Disable protenset will not happen during check flash region access operations.

Release 3.0.1
Changelog
---------------------------------------
- (Micro) Corrected typo in --programs help.

Release 3.0.0
Changelog
---------------------------------------
- (Major) Pin reset and reset cannot be combined.
- (Major) Added --deviceversion option.
- (Minor) Improved recover operation again.
- (Minor) Now --help and --version can be combined.
- (Minor) Corrected error with --pinreset when we have just protected with PALL.
- (Minor) Improved all erase operations, including adding system reset after them.
- (Minor) Added check for PALL protection before programming.
- (Minor) Better check for UICR conflicts when programming.
- (Micro) Corrected bug in programming under weird circunstances. Probably nobody hit this error.
- (Micro) Corrected typo in name of our company.
- (Micro) Cleaned up the calls for the information functions.
- (Micro) Corrected bug with pinreset when PALL. Now I inform the user that it may not work.
- (Micro) Eliminated bug, by checking PALL before calling disable_proten.
- (Micro) Corrected several errors in --programapp check for correctness.
- (Micro) Corrected bug in fwid option.
- (Micro) Updated device info after erasing.
- (Micro) Using default values for flash and ram sizes if the FICR is a little wrong.
- (Micro) Corrected bug in --fwid option check.
- (Micro) Corrected bug --recovers and --eraseapp. BOOTLOADERADDR in UICR was not being erased.
- (Micro) Corrected return value when only a secondary argument is given.
- (Micro) Corrected bug in --recovers.
- (Micro) Corrected bug in --memwr, --ramwr and --rawwr trying to write into FICR area.
- (Micro) Improve feedback on failed --recover.
- (Micro) Corrected small bug with --memrd and wrong --n parameter.
- (Micro) Corrected error when --memwr and PALL for certain registers.

Release 2.6.0
Changelog
---------------------------------------
- (Minor) Improved recover operation. Several attempts are made to recover the device, not just one.
- (Micro) Corrected some erros in error reporting.

Release 2.5.0
Changelog
---------------------------------------
- Clarified error messages and help of --programs.
- Added --fwid secondary option to --programs option.
- Corrected minor bug in --logids activity report.
- Corrected typo in error MisalignedOperation name.
- Corrected minor typo in --version report.
- Improved --ficrwritereg to avoid the erasing when only 1s are changed.
- Corrected typos in error reporting.
- Provided warnings with meaningless erase operations in the presence of --eraseall.
- UICR locations to download are checked during --program, --programapp and --programs to see if they are erased.
    If not, it will give an error.
- Removed bug in --ficrwritereg CLENR0 values.

Release 2.4.0
Changelog
---------------------------------------
- Corrected help for coderead.
- Added hexdump printing to memrd functionality.
- Corrected 2 typos in user feedback printing.
- Correct error in --quiet option. One command was not quiet.
- Provided popup window if several devices are present but none is sellected by -s or --snr in options.

Release 2.2.0
Changelog
---------------------------------------
- Corrected bug in --program checking the last byte is in code.
- Added --readregs function into the nrfjprog.
- Improved the check of the erased region when programming.

Release 2.1.1
Changelog
---------------------------------------
- Corrected bug in --readcode under certain conditions.
- Corrected bug in reporting of error in programs for missing CLENR0.

Release 2.1.0
Changelog
---------------------------------------
- Added support for old FICR files.
- Added read code area function, including checking if the user has read access tot he area requested.

Release 2.0.4
Changelog
---------------------------------------
- Registry search for the nrfjprog.dll location takes into account the version of nrfjprog.

Release 2.0.3
Changelog
---------------------------------------
- Beta release of new nrfjprog. Complete redesign of nrfjprog tool.

Release 1.0.7
Changelog
---------------------------------------
- Fixed the crash caused when using --verify option.
- --verify option speed optimized to be 4 times faster.

Release 1.0.6
Changelog
---------------------------------------
- Recompilation.

Release 1.0.5
Changelog
---------------------------------------
- Fixed a problem in --program and --programs.

Release 1.0.4
Changelog
---------------------------------------
- Fixed an incorrect parameter when reading a registry value.
- Fixed minor typos in the std out comment.
- Fixed pin reset bug.

Release 1.0.3
Changelog
---------------------------------------
- Fixed the utility to work again with WinXP-32-bit machines
- Added verify option that can verify device memory contents with given hex file.

Release 1.0.2
Changelog
---------------------------------------
- Minor bug fix.

Release 1.0.1
Changelog
---------------------------------------
- fixing bug with buffer size.

Release 1.0.0
Changelog
---------------------------------------
- Code Reviewed: Bug fixes + optimizations.
- default output for --memrd + --n option, when not using --w, is changed from 8-bit to 32-bit as that will be used more.
- adding -q --quiet option (do not print any log)
- adding --dso disable system off until next reset.
- fixing bug with pin reset that did not switch the debug mode back to SWD from JTAG

Release 0.2.5
Changelog
---------------------------------------
-- removing uicrwritereg option as same functionality can be achieved using memwr option.
-- using --memwr for non-flash addresses will not configure nvmc for write/read/erase enable.
-- adding --hexuicrinfo that reads the hex file and dumps (to stdout) UICR-> CR0, RBPCONF and/or FWID if they are to be programmed from hex file
-- changed the default J-Link speed to 10MHz (previous 1MHz) if not set expplicitly by --clockspeed option
-- added --dmemwr option, dumb write instruction to cpu. This option is not flash aware. It takes the same arguments like memwr,

Known Issuees
----------------------
-- writing to a flash memory using --memwr option is erasing the page first before write, this is done within segger dll and this issue
   will be addressed very soon.

Release 0.2.4
Differences from the previous release
---------------------------------------
-- implemented --w option for --memrd. you can dump values in either 8(Default). 16 or 32 bit format
-- implemented --recover option which can be used to disable system off and erase code regions and then enable system off again
       can be used to recover chips in system off without wakeup source configured

Release 0.2.3
Differences from the previous release
---------------------------------------
- fixed a bug that is causing the pop up window with multiple seggers connected and even if serial number was given as argument.

Release 0.2.2
Differences from the previous release
---------------------------------------
 - fixed bug that --n option (as in --memrd 0XSomething --n 20) was considering the number in hex, its a number of bytes
       in decimal radix 10.
 - added -p, --pinreset option to do a hard pin reset
 - adding --run option to set --pc (program counter) and --sp (stack pointer)
 - added  --hexuicrinfo    <hex_file>         Reads the hex file and dumps (to stdout) UICR-> CR0, RBPCONF and/or FWID if they are to be programmed from hex file
                                              Note: only those registers are shown whose addresses exist in the hex file
 - more bug fixes.

Release 0.2.1
Differences from the previous release
---------------------------------------
 - bug with the utility that did not work on XP (now fixed)
 - "--rbp CR0" is not allowed when CR0 is not defined in FICR or UICR. (use --clenr0 to set the CR0 first)
 - --rbp is allowed to be used with --program (application) option
 - auto backup file extention changed from .txt to .log which are easy for auto clean operations.
 - --eraseuicr option added
 - added info that -e, --eraseall is not available for factory programmed chips
 - added more checks for eraseall and eraseuicr for factory programmed and non factory programmed.
 - added --memrd option (courtesy nrfprog, works exactly the same way)
 - added --memwr option

Release 0.2
Differences from the previous release
---------------------------------------
 - Adding -v or --version option to know the version of this utility
 - EraseAll will not do an implicit reset (but --programs will do implicit eraseall and a reset)
 - --clenr0 and/or --rbp options cannot be used with --program
 - cannot use --clenr0 option with --programs if the hex file is programming to UICR->CLENR0
 - cannot use --rbp option with --programs if the hex file is programming to UICR->RBP
 - hex files can now contain uicr address ranges (usable only by --programs).
 - bufferring all flash segment writes so that user sees only one write operation per hex file
 - check first in the local directory for JLinkARM.dll (useful for standalone apps) before checking registry for its installed path.
 - hex files cannot contain uicr address range with --program option
 - check application base address to match CR1 base address (on protected chips), if not match then return error with flash untouched.
 - removing --bin option to keep it simple
 - added few more error codes
 - wrong serial number given as the argument will return error and the program will quit

Release 0.1.3
Differences from the previous release
----------------------------------------
 - added error codes to handle different errors and return to the caller (for error codes @ref nrfjprog.h)
 - added --rbp option to enable readback protection for cr0 and cr0+cr1
 - when using --programs option readback protection is not changed (in earlier version using this option would set RBPCONF to CR0)
 - --clenr0 option must now be used with --programs to protect the softdevice else programming softdevice will fail
 - added --readuicr option to read uicr page into given file
 - removed flashing binary file check and support for --program
 - able to read uicr address range from hex file and write to UICR page

Release 0.1.2
differences from the previous release
---------------------------------------
 - few bug fixes
 - reducing wait time for each operation by correctly waiting on the ready flag
 - adding reset -r option (-e option does an reset implicitly)
 - added --uicrwritereg value to write to uicr register (remember only 1's can be changed to 0's)
 - Searching segger installation in HKEY_LOCAL_MACHINE also for buildservers to work properly. Segger will include
            in their next release to add a key to HKEY_LOCAL_MACHINE root

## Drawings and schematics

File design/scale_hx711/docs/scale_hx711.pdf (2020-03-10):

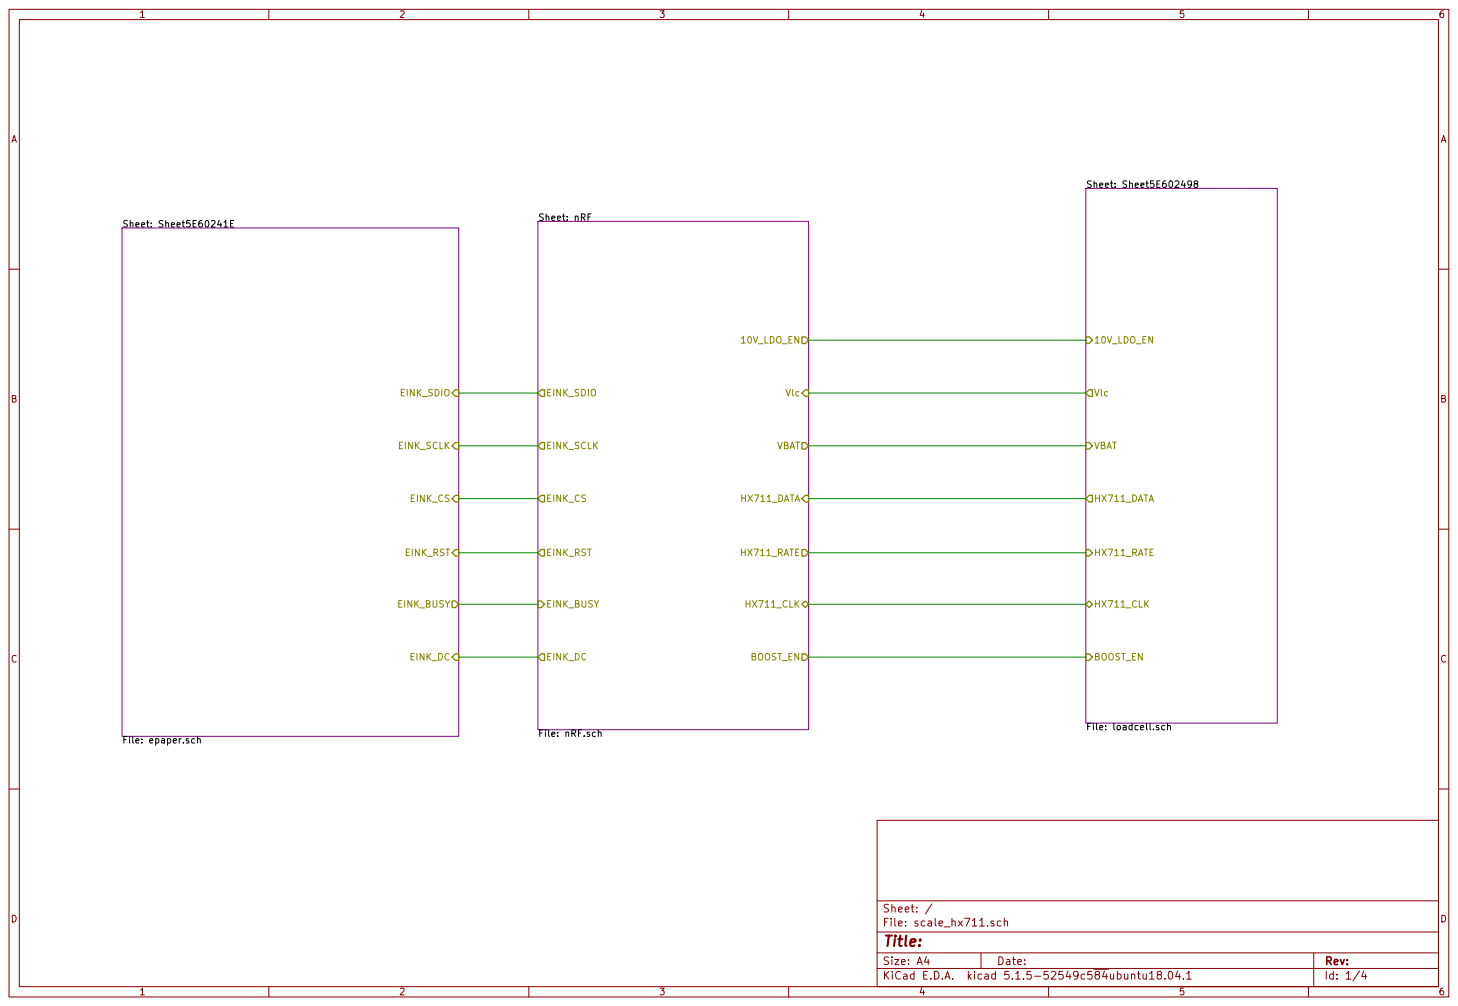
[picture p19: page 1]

Sheet: Sheet5E602498 File: loadcell.sch VBAT HX711_RATE HX711_DATA HX711_CLK

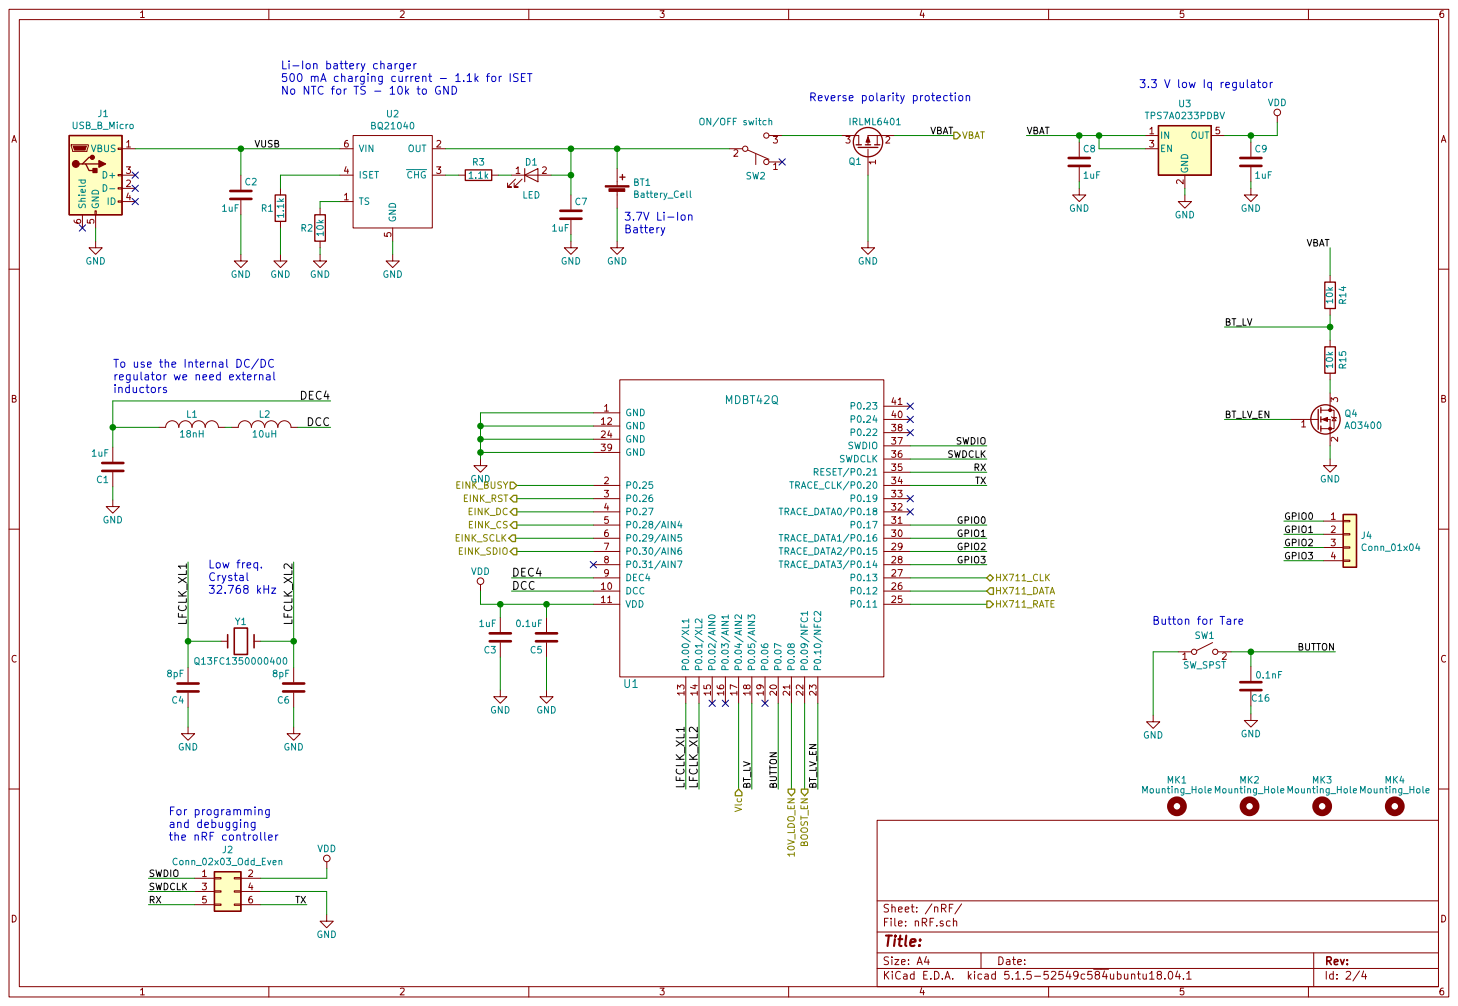
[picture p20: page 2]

Li-Ion battery charger
500 mA charging current - 1.1k for ISET
No NTC for TS - 10k to GND
VUSB Low freq.

2 EN 3 OUT 5 U3 TPS7A0233PDBV GND GND

To use the Internal DC/DC
regulator we need external

Crystal 32.768 kHz For programming

Id: 2/4 Title: File: nRF.sch Sheet: /nRF/

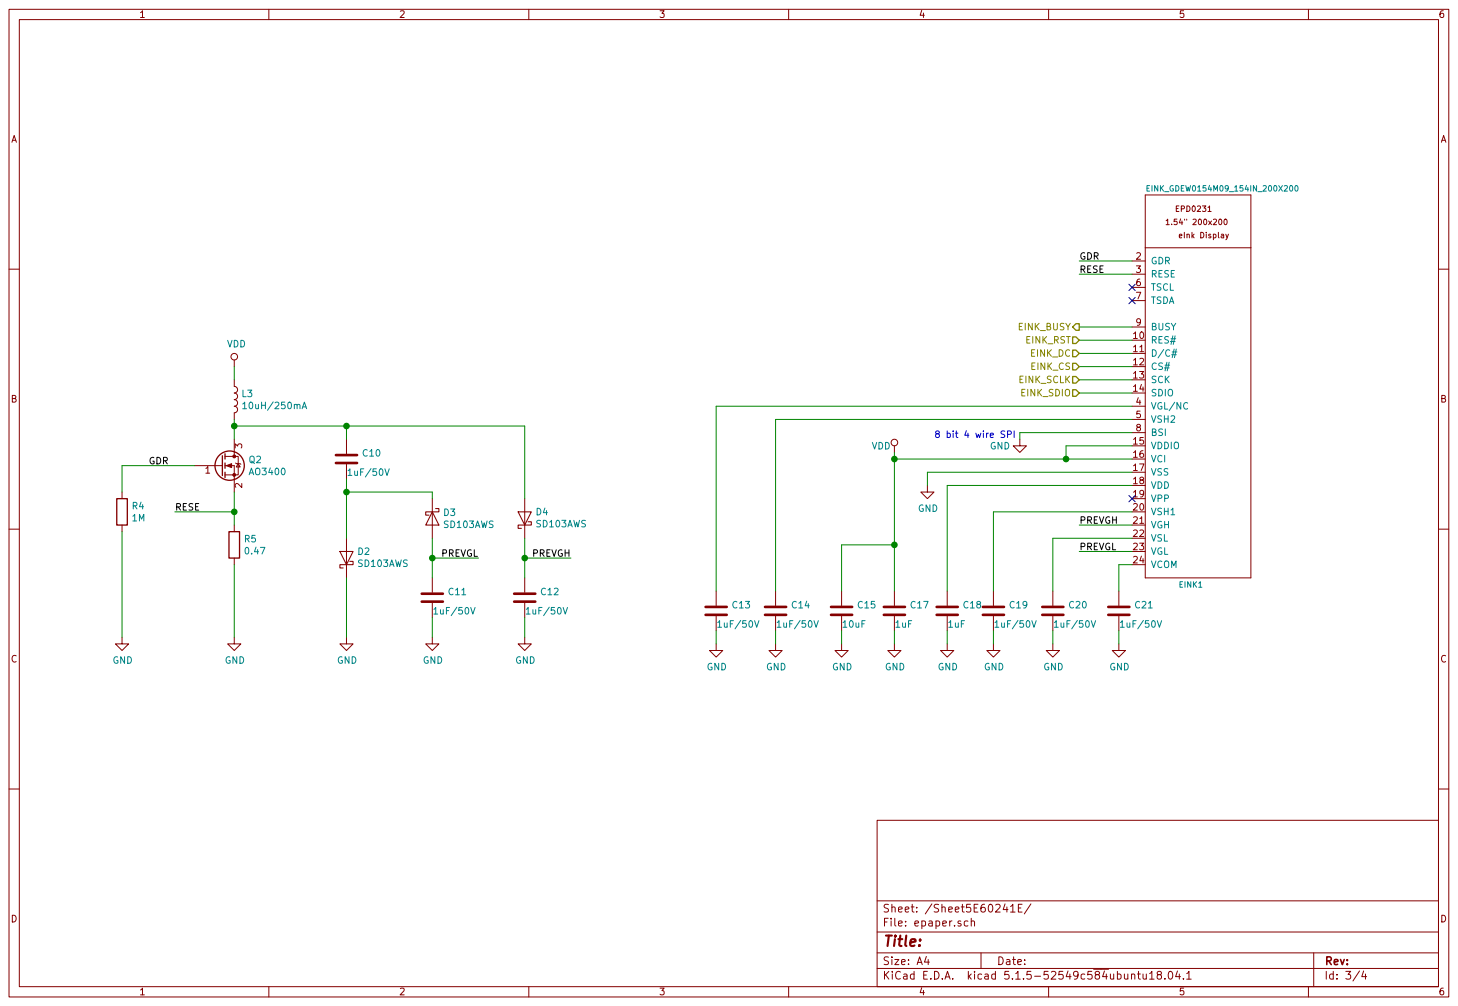
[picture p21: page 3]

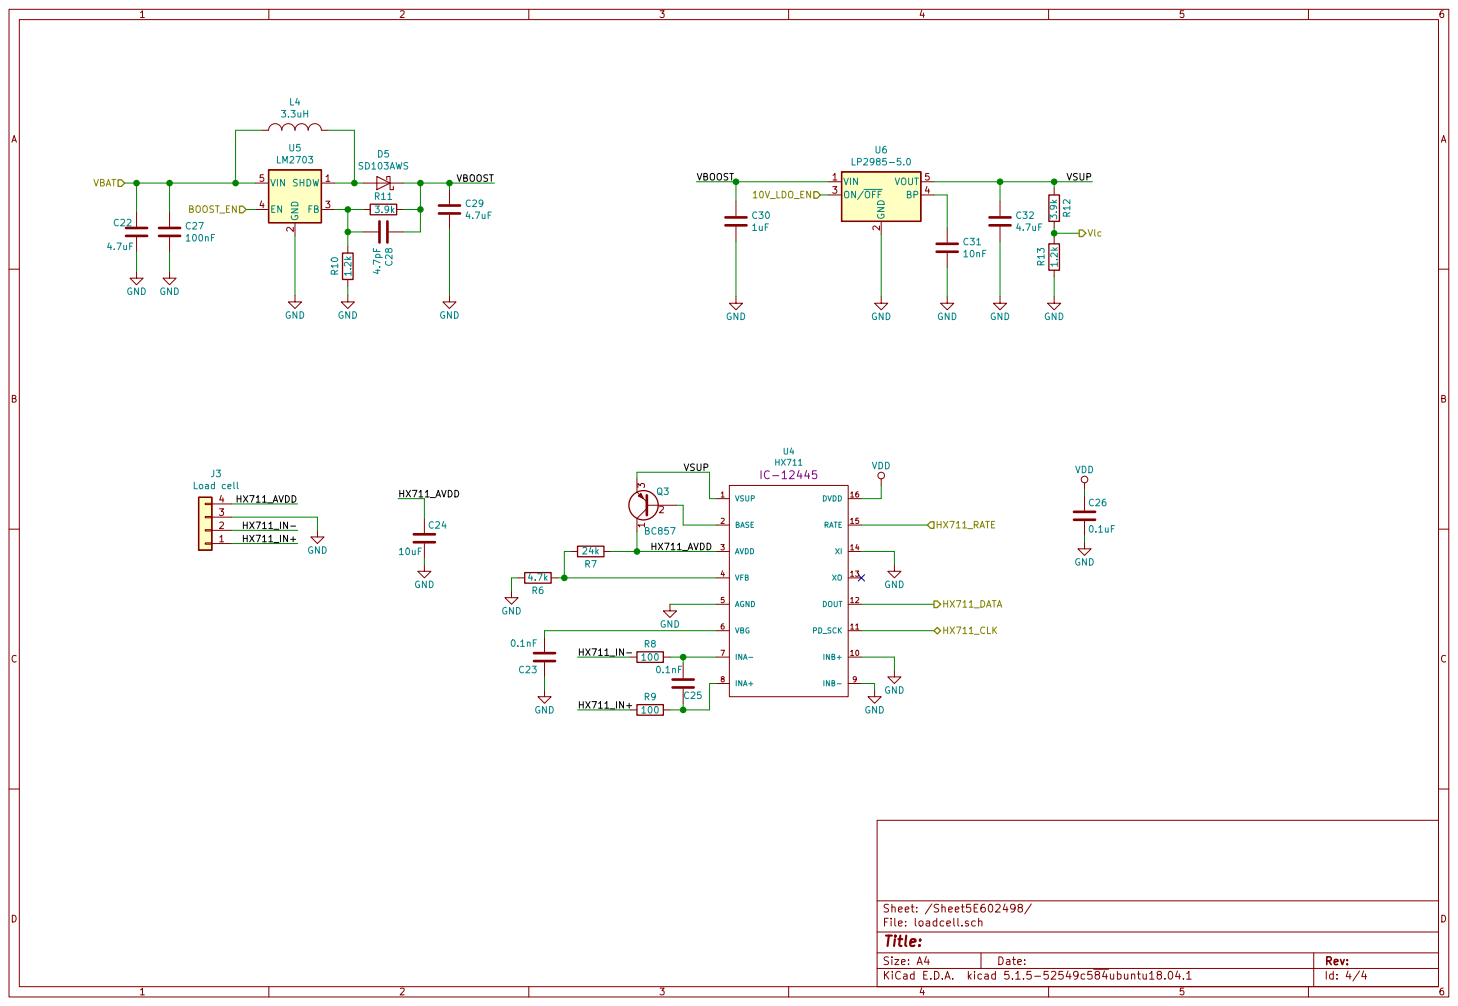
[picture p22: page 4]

2 ON/OFF 3 BP 4 VOUT 5 U6

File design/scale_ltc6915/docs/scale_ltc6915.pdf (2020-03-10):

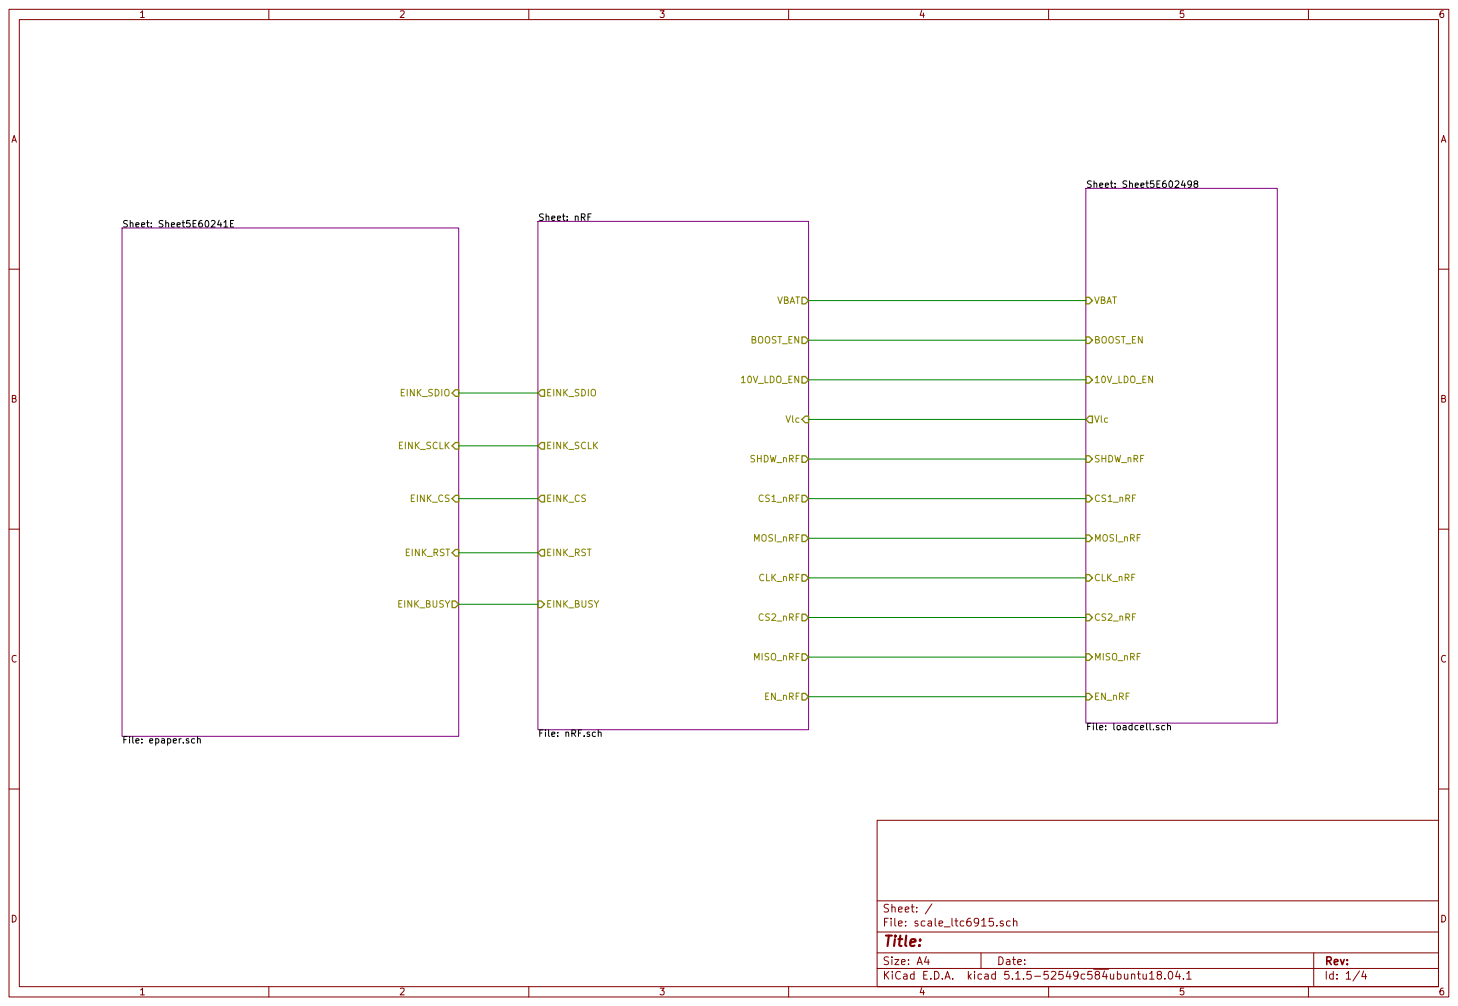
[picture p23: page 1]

Sheet: Sheet5E602498 File: loadcell.sch

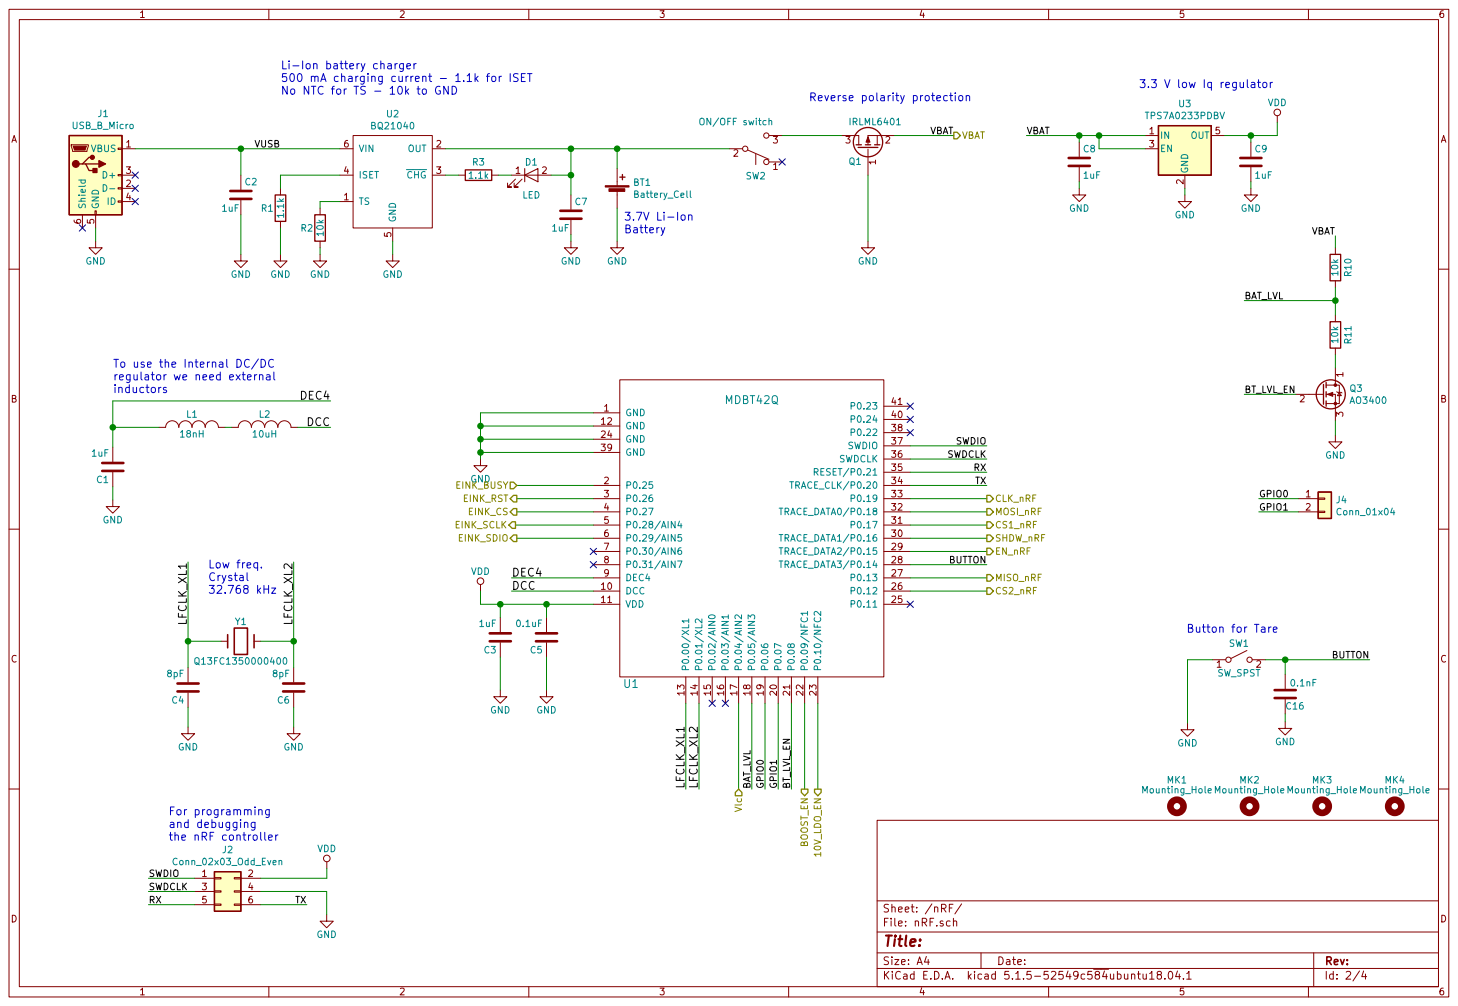
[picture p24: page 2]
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

To use the Internal DC/DC
regulator we need external

Id: 2/4 Title: File: nRF.sch Sheet: /nRF/

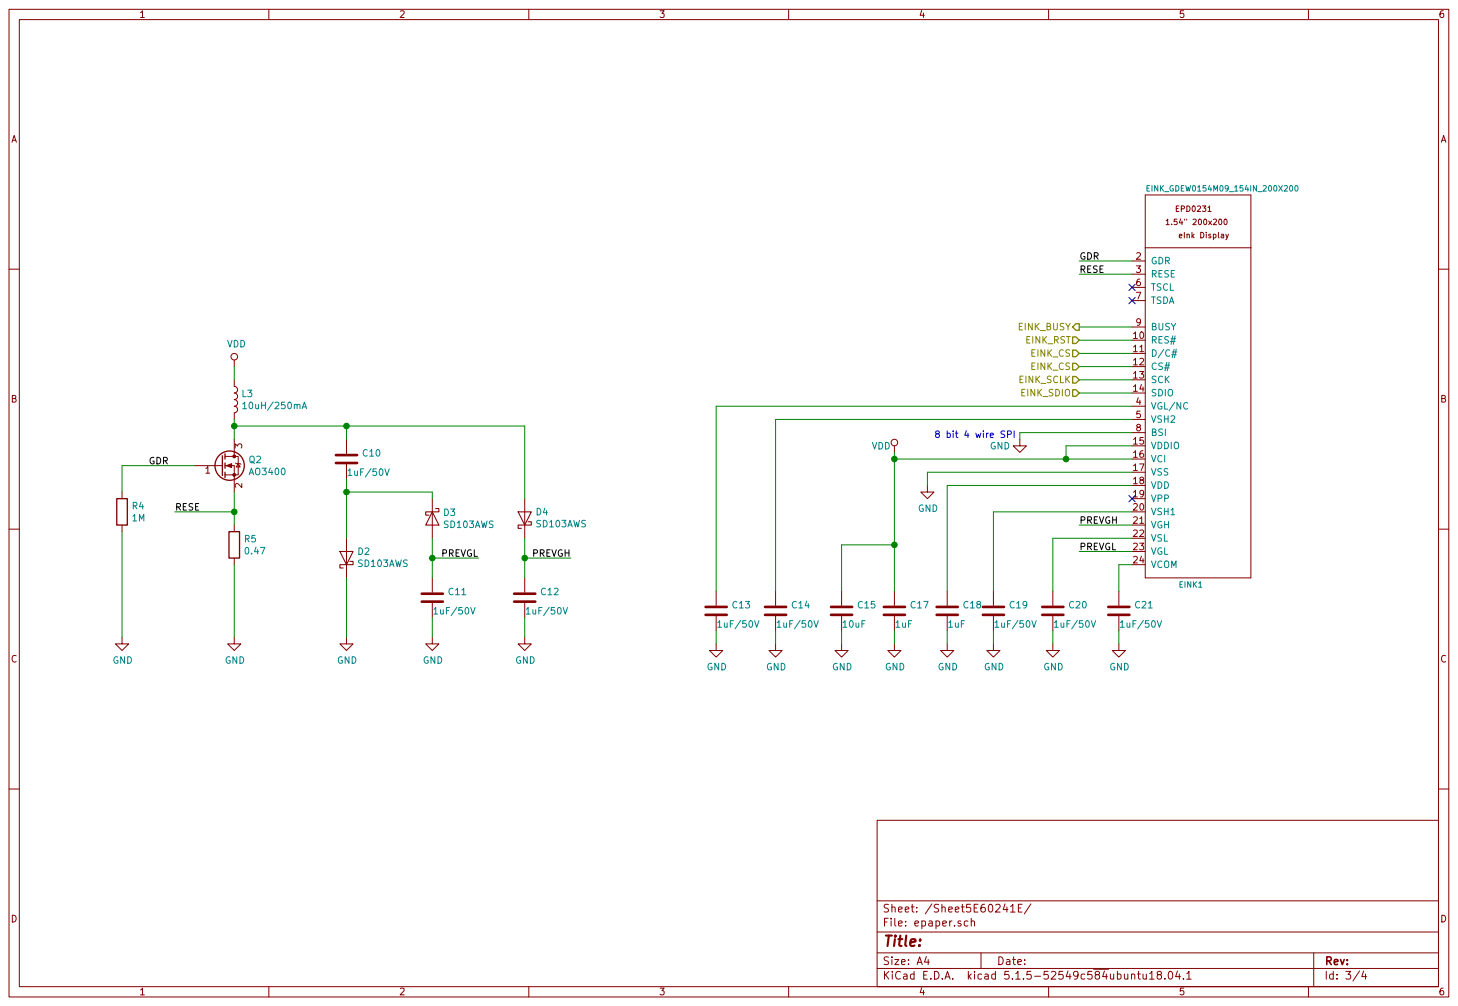
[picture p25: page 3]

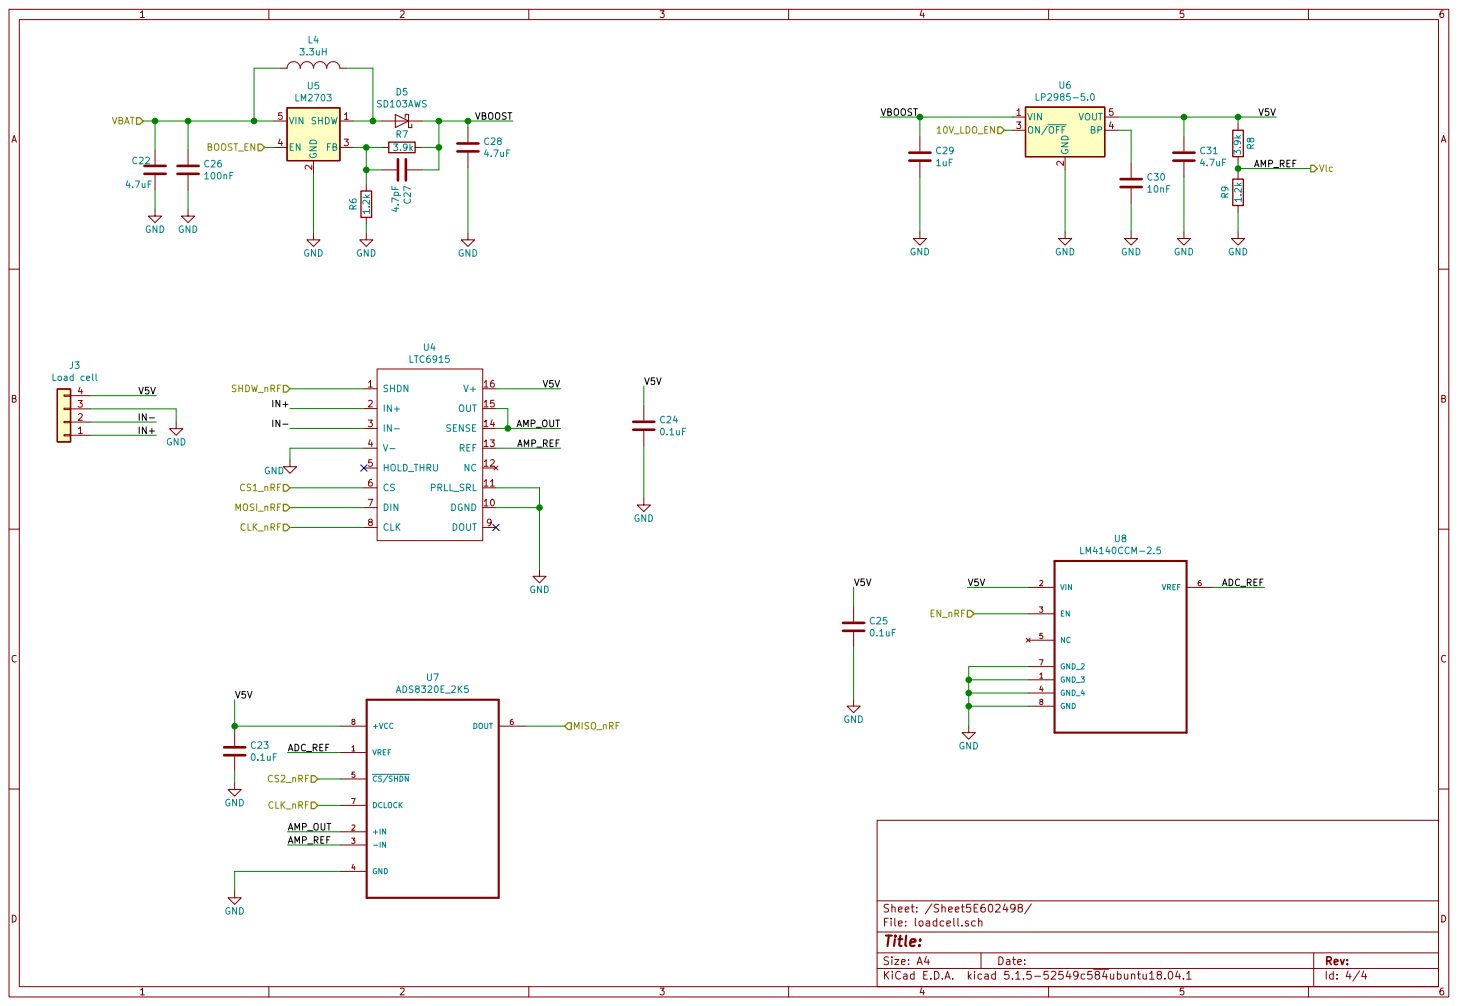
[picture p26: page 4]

2 ON/OFF 3 BP 4 VOUT 5 U6

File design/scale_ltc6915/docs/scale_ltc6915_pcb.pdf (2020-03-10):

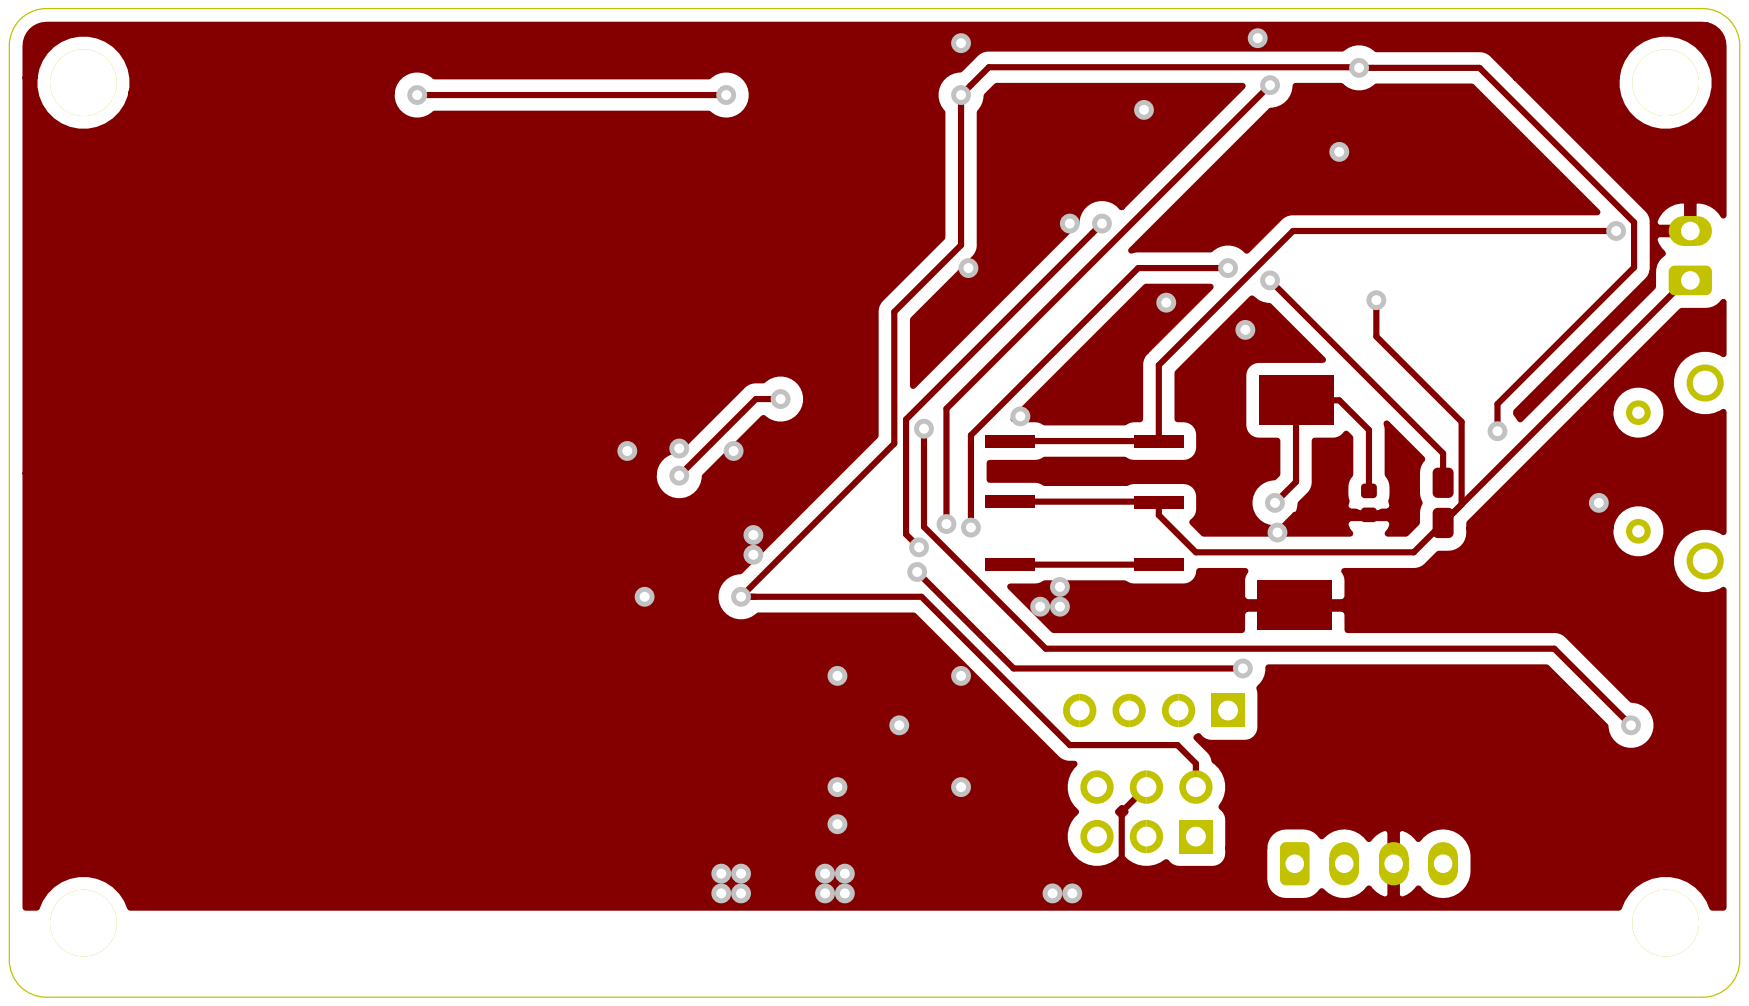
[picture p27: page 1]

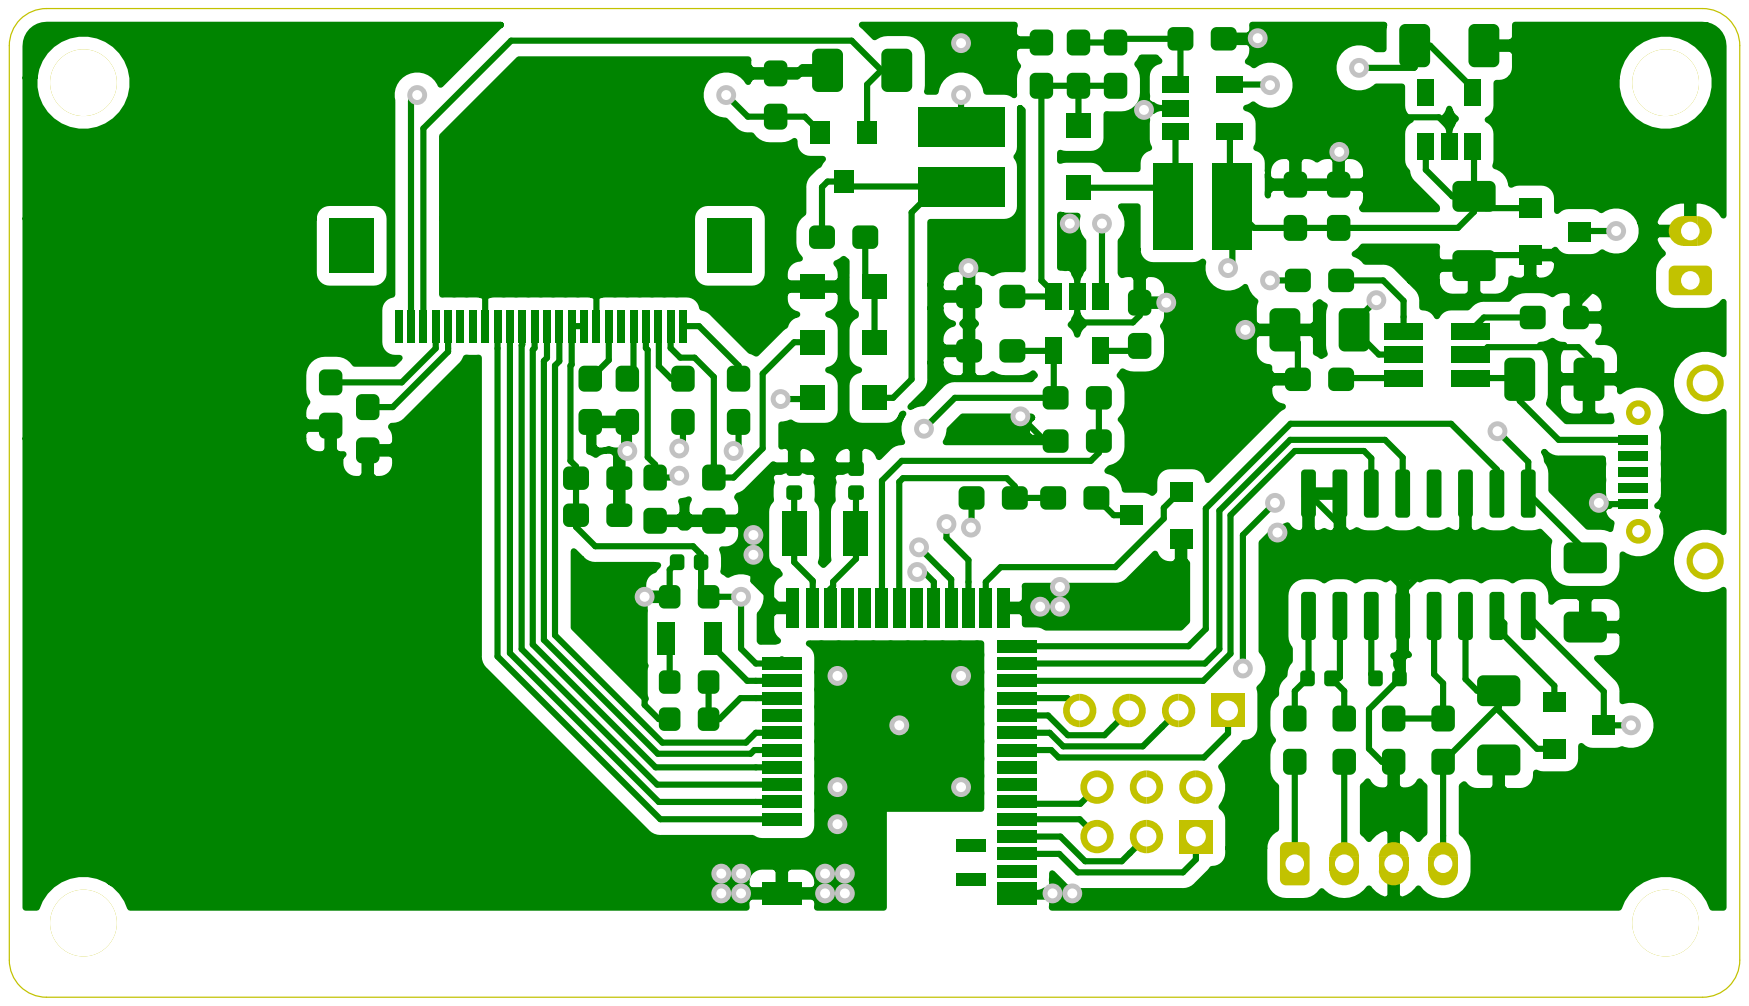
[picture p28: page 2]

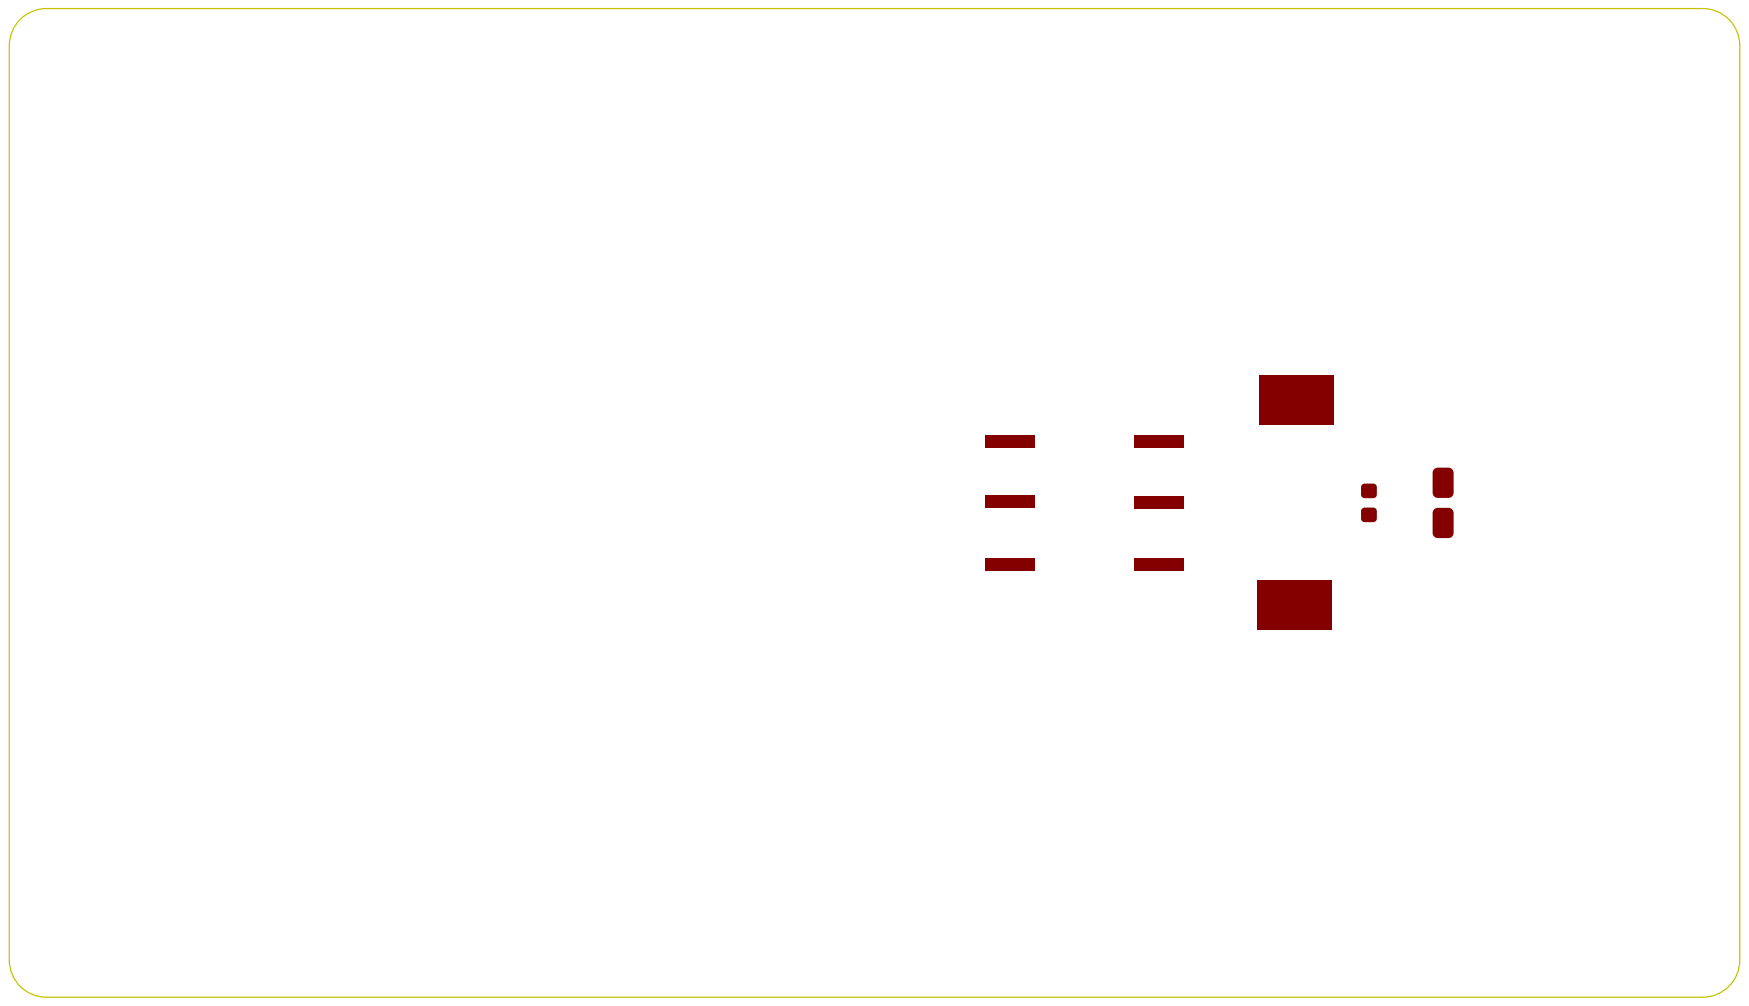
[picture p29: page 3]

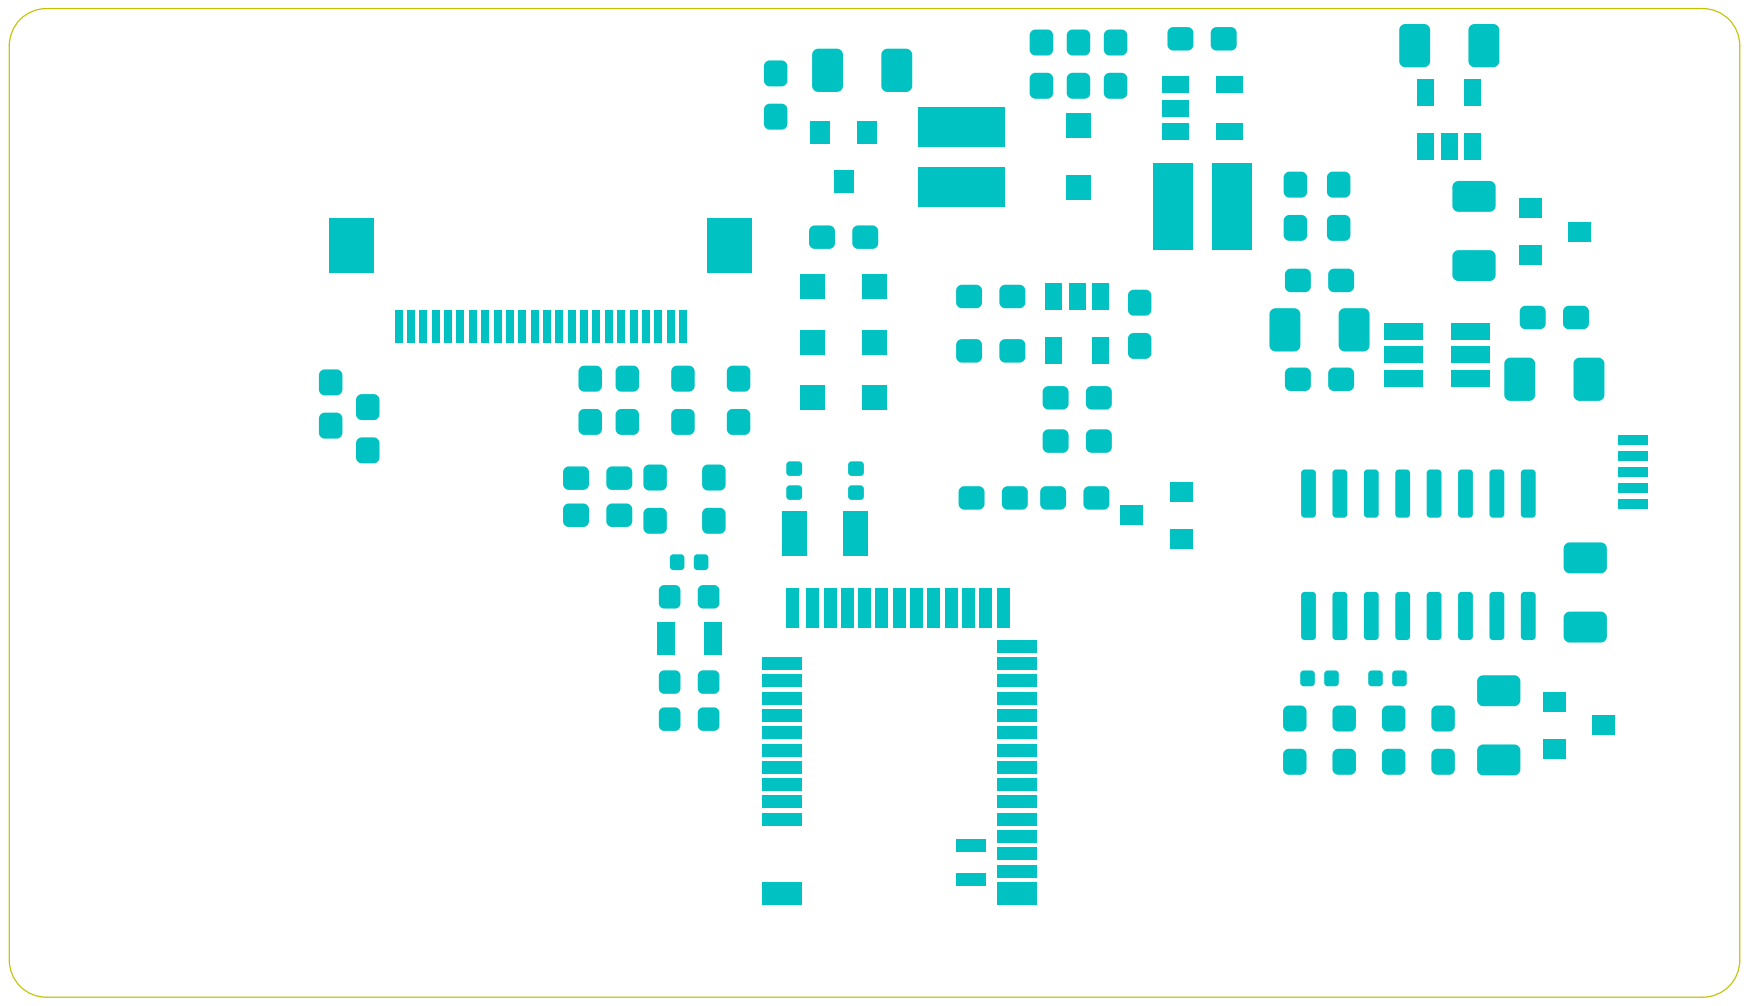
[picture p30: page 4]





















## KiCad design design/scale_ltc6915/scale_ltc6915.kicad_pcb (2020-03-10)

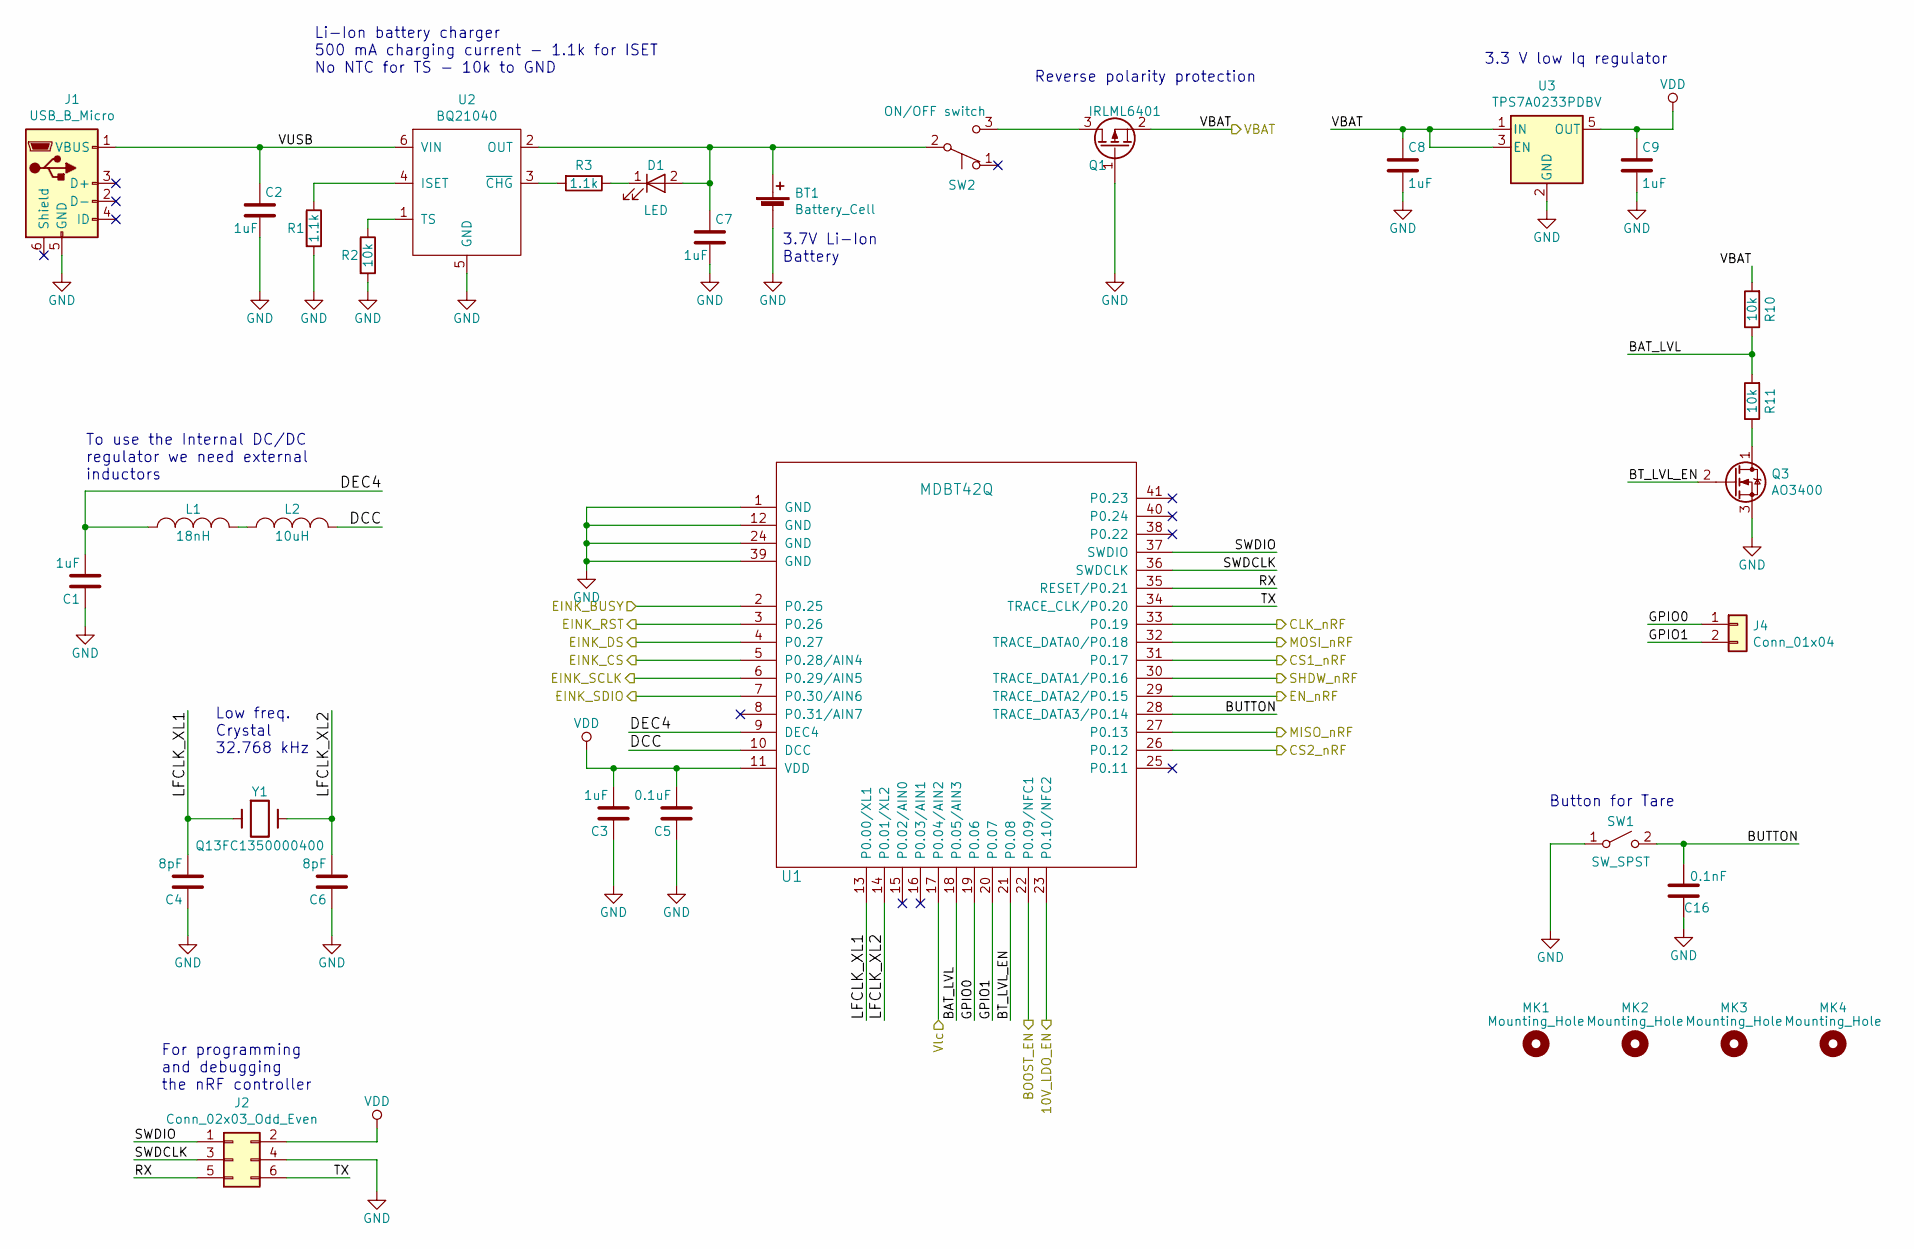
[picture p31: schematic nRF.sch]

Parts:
BT1: Battery_Cell; JST_PH_B2B-PH-K_1x02_P2.00mm_Vertical
C1, C3: 1uF; C_0603_1608Metric
C2, C7, C8, C9: 1uF; C_1206_3216Metric
C4, C6: 8pF; C_0402_1005Metric
C5: 0.1uF; C_0402_1005Metric
C16: 0.1nF; C_0402_1005Metric
D1: LED; LED_0603_1608Metric_Castellated
J1: USB_B_Micro; Micro_usb_connector_4_THT_pads
J2: Conn_02x03_Odd_Even; PinHeader_2x03_P2.00mm_Vertical
J4: Conn_01x04; PinHeader_1x02_P2.00mm_Vertical
L1: 18nH; C_0603_1608Metric
L2: 10uH; L_0805
MK1, MK2, MK3, MK4: Mounting_Hole; MountingHole_2.7mm_M2.5
Q1: IRLML6401; SOT-23
Q3: AO3400; SOT-23
R1, R3: 1.1k; R_0603_1608Metric_Pad1.05x0.95mm_HandSolder
R2, R10, R11: 10k; R_0603_1608Metric_Pad1.05x0.95mm_HandSolder
SW1: SW_SPST; SMD Tactile Switch_3x6x2.5mm
SW2: ON/OFF switch; Slide Switch SMD 2P2T _6pins
U1: MDBT42Q; mdbt42Q
U2: BQ21040; SOT-23-6_Handsoldering
U3: TPS7A0233PDBV; SOT-23-5
Y1: Q13FC1350000400; Q13FC1350000400_SMD Crystals 32.768KHz

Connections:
/Sheet5E60241E/EINK_BUSY: U1.2 (P0.25); also elsewhere on the board
/Sheet5E60241E/EINK_CS: U1.5 (P0.28/AIN4); also elsewhere on the board
/Sheet5E60241E/EINK_DS: U1.4 (P0.27); also elsewhere on the board
/Sheet5E60241E/EINK_RST: U1.3 (P0.26); also elsewhere on the board
/Sheet5E60241E/EINK_SCLK: U1.6 (P0.29/AIN5); also elsewhere on the board
/Sheet5E60241E/EINK_SDIO: U1.7 (P0.30/AIN6); also elsewhere on the board
/Sheet5E602498/10V_LDO_EN: U1.23 (P0.10/NFC2); also elsewhere on the board
/Sheet5E602498/BOOST_EN: U1.22 (P0.09/NFC1); also elsewhere on the board
/Sheet5E602498/CLK_nRF: U1.33 (P0.19); also elsewhere on the board
/Sheet5E602498/CS1_nRF: U1.31 (P0.17); also elsewhere on the board
/Sheet5E602498/CS2_nRF: U1.26 (P0.12); also elsewhere on the board
/Sheet5E602498/EN_nRF: U1.29 (TRACE_DATA2/P0.15); also elsewhere on the board
/Sheet5E602498/MISO_nRF: U1.27 (P0.13); also elsewhere on the board
/Sheet5E602498/MOSI_nRF: U1.32 (TRACE_DATA0/P0.18); also elsewhere on the board
/Sheet5E602498/SHDW_nRF: U1.30 (TRACE_DATA1/P0.16); also elsewhere on the board
/Sheet5E602498/VBAT: C8.1, Q1.2 (G), R10.2, U3.1 (IN), U3.3 (EN); also elsewhere on the board
/Sheet5E602498/Vlc: U1.17 (P0.04/AIN2); also elsewhere on the board
/nRF/BAT_LVL: R10.1, R11.2, U1.18 (P0.05/AIN3)
/nRF/BT_LVL_EN: Q3.2 (G), U1.21 (P0.08)
/nRF/BUTTON: C16.2, SW1.2 (B), U1.28 (TRACE_DATA3/P0.14)
/nRF/DCC: L2.2, U1.10 (DCC)
/nRF/DEC4: C1.2, L1.1, U1.9 (DEC4)
/nRF/GPIO0: J4.1, U1.19 (P0.06)
/nRF/GPIO1: J4.2, U1.20 (P0.07)
/nRF/LFCLK_XL1: C4.2, U1.13 (P0.00/XL1), Y1.1
/nRF/LFCLK_XL2: C6.2, U1.14 (P0.01/XL2), Y1.2
/nRF/RX: J2.5, U1.35 (RESET/P0.21)
/nRF/SWDCLK: J2.3, U1.36 (SWDCLK)
/nRF/SWDIO: J2.1, U1.37 (SWDIO)
/nRF/TX: J2.6, U1.34 (TRACE_CLK/P0.20)
/nRF/VUSB: C2.1, J1.1 (VBUS), U2.6 (VIN)
GND: BT1.2, C1.1, C2.2, C3.1, C4.1, C5.1, C6.1, C7.2, C8.2, C9.2, C16.1, J1.5 (GND), J2.4, Q1.1 (D), Q3.3 (S), R1.2, R2.2, SW1.1 (A), U1.1 (GND), U1.12 (GND), U1.24 (GND), U1.39 (GND), U2.5 (GND), U3.2 (GND); also elsewhere on the board
unnamed: BT1.1, C7.1, D1.2 (A), SW2.2 (B), U2.2 (OUT)
unnamed: D1.1 (K), R3.1
unnamed: L1.2, L2.1
unnamed: Q1.3 (S), SW2.3 (C)
unnamed: Q3.1 (D), R11.1
unnamed: R1.1, U2.4 (ISET)
unnamed: R2.1, U2.1 (TS)
unnamed: R3.2, U2.3 (~CHG)
VDD: C3.2, C5.2, C9.1, J2.2, U1.11 (VDD), U3.5 (OUT); also elsewhere on the board

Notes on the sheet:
3.7V Li-Ion Battery
Reverse polarity protection
Button for Tare
To use the Internal DC/DC regulator we need external inductors
For programming and debugging the nRF controller
Low freq. Crystal 32.768 kHz
3.3 V low Iq regulator
Li-Ion battery charger 500 mA charging current - 1.1k for ISET No NTC for TS - 10k to GND

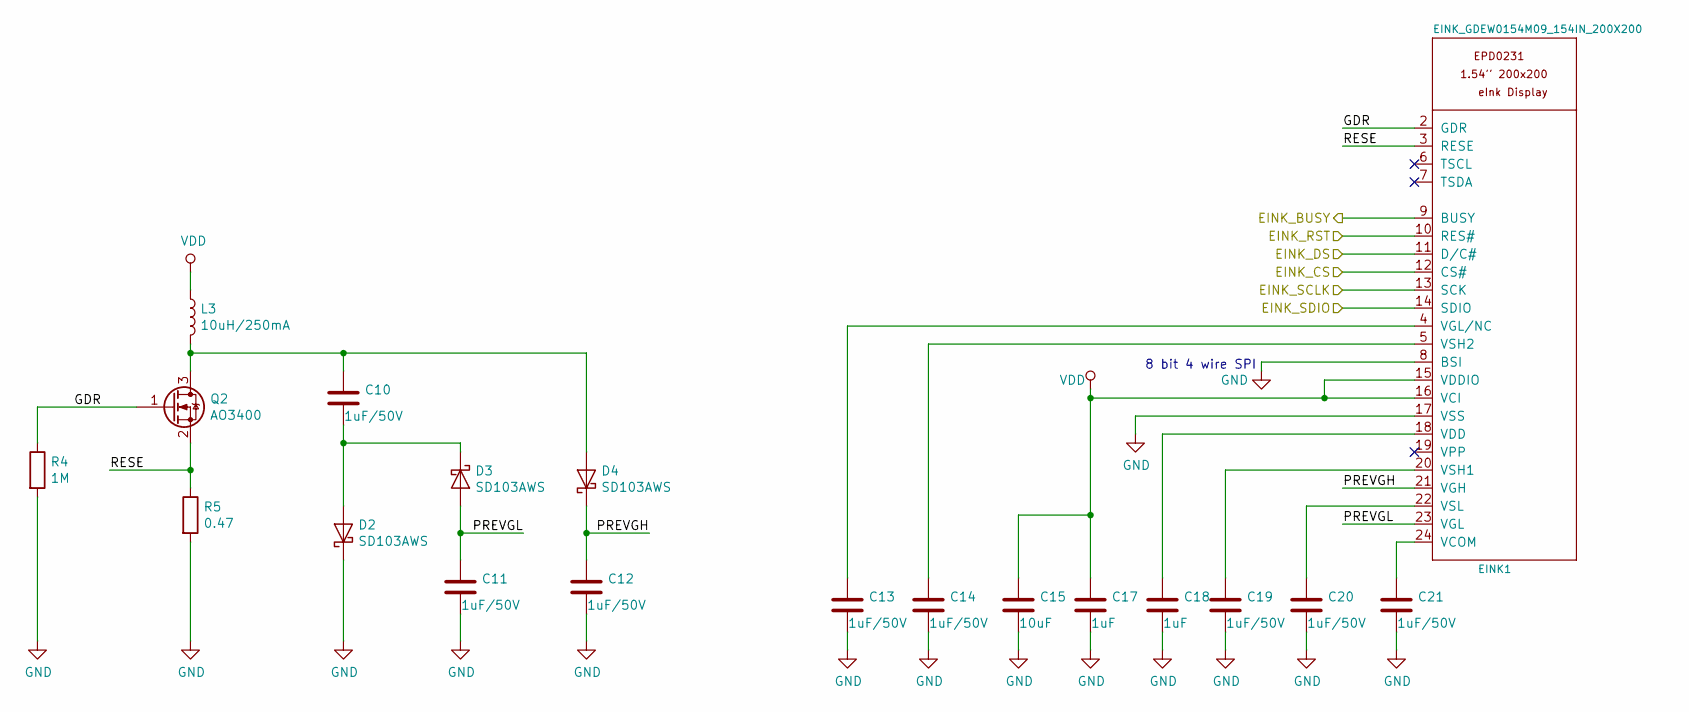
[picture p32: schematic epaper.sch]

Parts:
C10, C11, C12, C13, C14, C19, C20, C21: 1uF/50V; C_0603_1608Metric_Pad1.05x0.95mm_HandSolder
C15: 10uF; C_0603_1608Metric_Pad1.05x0.95mm_HandSolder
C17, C18: 1uF; C_0603_1608Metric_Pad1.05x0.95mm_HandSolder
D2, D3, D4: SD103AWS; D_SOD-323_HandSoldering
EINK1: EINK_GDEW0154M09_154IN_200X200; Hirose_FH12-24S-0.5SH_1x24-1MP_P0.50mm_Horizontal
L3: 10uH/250mA; L_3.5x3.0mm_CD30D22
Q2: AO3400; SOT-23
R4: 1M; R_0603_1608Metric_Pad1.05x0.95mm_HandSolder
R5: 0.47; R_1206_3216Metric

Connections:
/Sheet5E60241E/EINK_BUSY: EINK1.9 (BUSY); also elsewhere on the board
/Sheet5E60241E/EINK_CS: EINK1.12 (CS#); also elsewhere on the board
/Sheet5E60241E/EINK_DS: EINK1.11 (D/C#); also elsewhere on the board
/Sheet5E60241E/EINK_RST: EINK1.10 (RES#); also elsewhere on the board
/Sheet5E60241E/EINK_SCLK: EINK1.13 (SCK); also elsewhere on the board
/Sheet5E60241E/EINK_SDIO: EINK1.14 (SDIO); also elsewhere on the board
/Sheet5E60241E/GDR: EINK1.2 (GDR), Q2.1 (G), R4.1
/Sheet5E60241E/PREVGH: C12.1, D4.1 (K), EINK1.21 (VGH)
/Sheet5E60241E/PREVGL: C11.1, D3.2 (A), EINK1.23 (VGL)
/Sheet5E60241E/RESE: EINK1.3 (RESE), Q2.2 (S), R5.1
GND: C11.2, C12.2, C13.2, C14.2, C15.2, C17.2, C18.2, C19.2, C20.2, C21.2, D2.1 (K), EINK1.8 (BSI), EINK1.17 (VSS), R4.2, R5.2; also elsewhere on the board
unnamed: C10.1, D4.2 (A), L3.2, Q2.3 (D)
unnamed: C10.2, D2.2 (A), D3.1 (K)
unnamed: C13.1, EINK1.4 (VGL/NC)
unnamed: C14.1, EINK1.5 (VSH2)
unnamed: C18.1, EINK1.18 (VDD)
unnamed: C19.1, EINK1.20 (VSH1)
unnamed: C20.1, EINK1.22 (VSL)
unnamed: C21.1, EINK1.24 (VCOM)
VDD: C15.1, C17.1, EINK1.15 (VDDIO), EINK1.16 (VCI), L3.1; also elsewhere on the board

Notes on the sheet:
8 bit 4 wire SPI

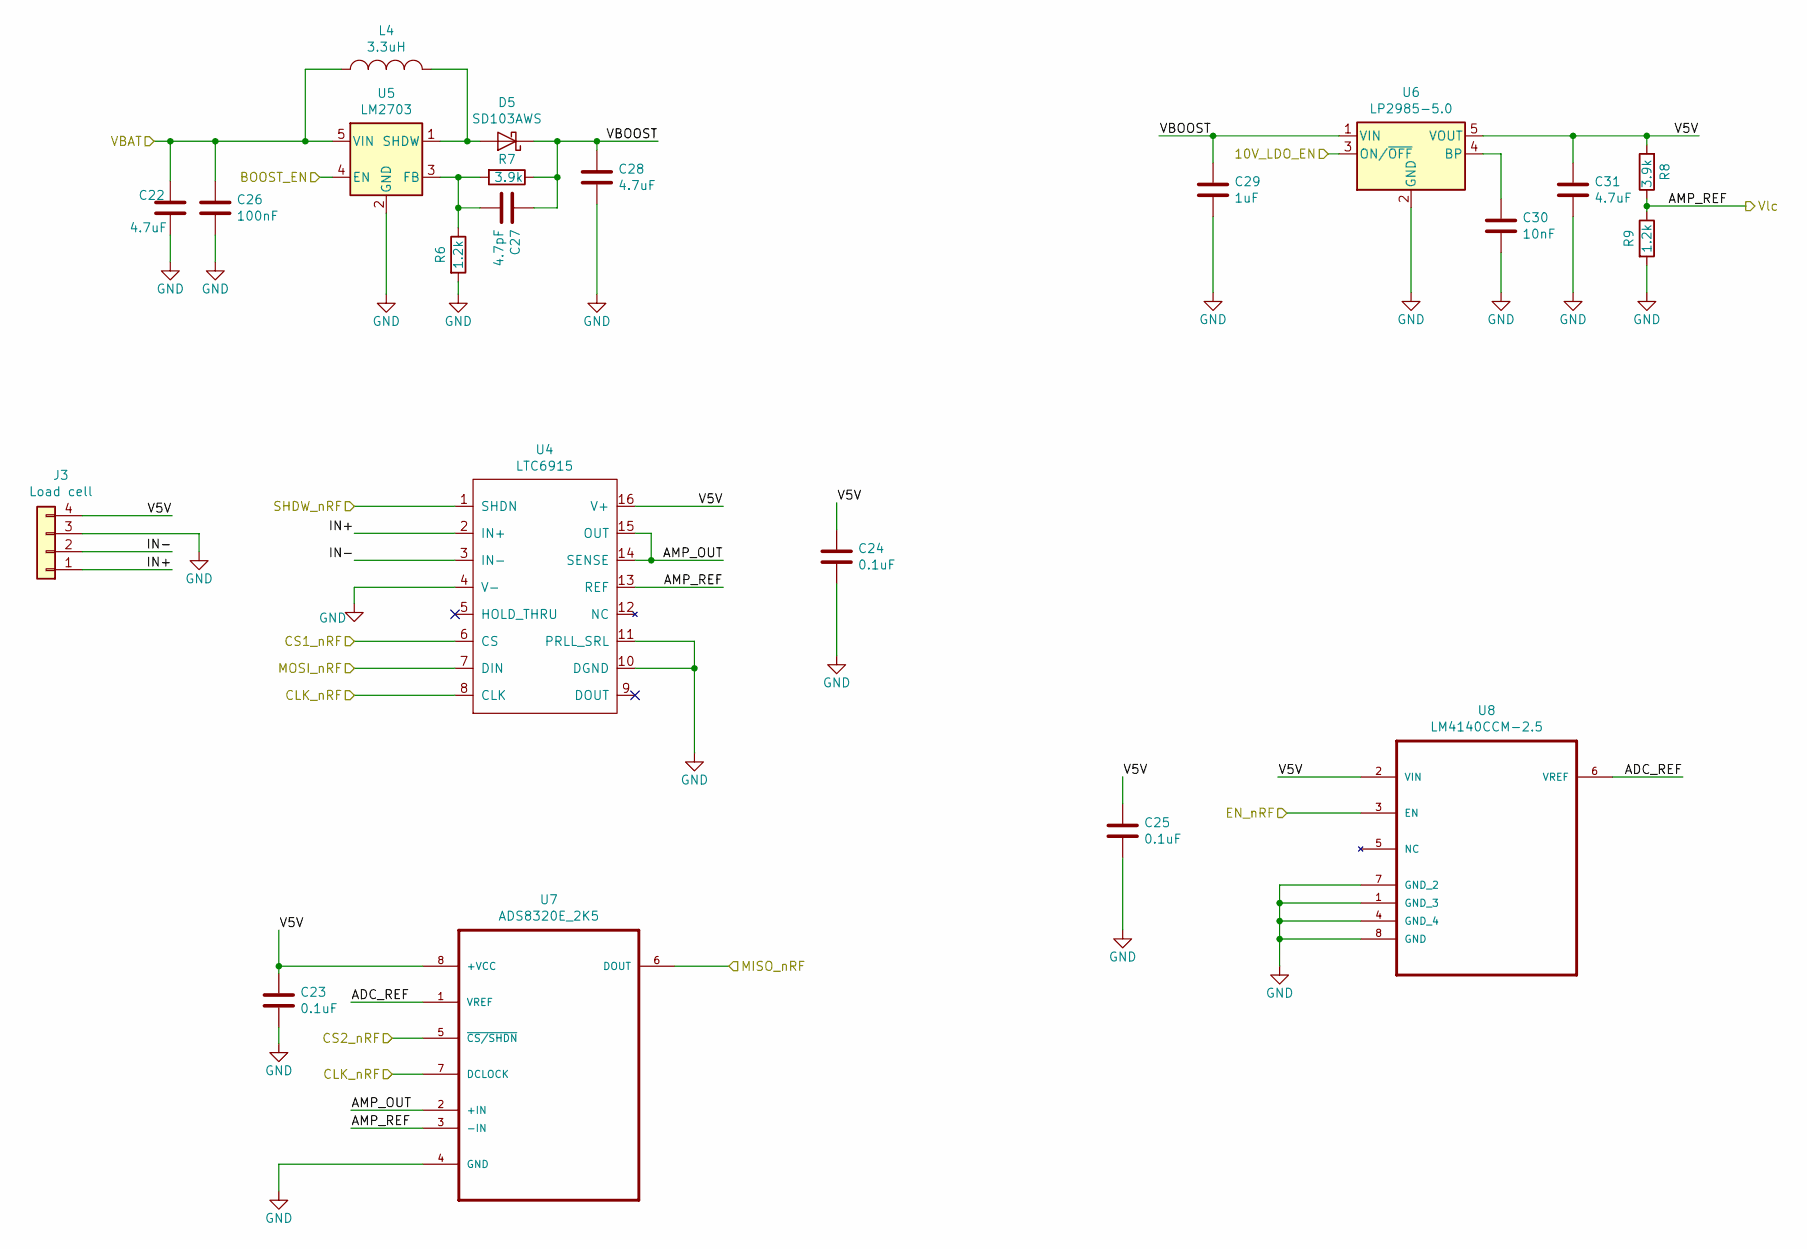
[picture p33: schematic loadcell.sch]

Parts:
C22, C28, C31: 4.7uF; C_0603_1608Metric_Pad1.05x0.95mm_HandSolder
C23, C24, C25: 0.1uF; C_0603_1608Metric_Pad1.05x0.95mm_HandSolder
C26: 100nF; C_0603_1608Metric_Pad1.05x0.95mm_HandSolder
C27: 4.7pF; C_0603_1608Metric_Pad1.05x0.95mm_HandSolder
C29: 1uF; C_0603_1608Metric_Pad1.05x0.95mm_HandSolder
C30: 10nF; C_0603_1608Metric_Pad1.05x0.95mm_HandSolder
D5: SD103AWS; D_SOD-323_HandSoldering
J3: Load cell; JST_PH_B4B-PH-K_1x04_P2.00mm_Vertical
L4: 3.3uH; L_3.5x3.0mm_CD30D22
R6, R9: 1.2k; R_0603_1608Metric_Pad1.05x0.95mm_HandSolder
R7, R8: 3.9k; R_0603_1608Metric_Pad1.05x0.95mm_HandSolder
U4: LTC6915; SSOP-16_3.9x4.9mm_P0.635mm
U5: LM2703; SOT-23-5
U6: LP2985-5.0; SOT-23-5
U7: ADS8320E_2K5; VSSOP-8_3.0x3.0mm_P0.65mm
U8: LM4140CCM-2.5; SOIC-8_3.9x4.9mm_P1.27mm

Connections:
/Sheet5E602498/10V_LDO_EN: U6.3 (ON/~OFF~); also elsewhere on the board
/Sheet5E602498/ADC_REF: U7.1 (VREF), U8.6 (VREF)
/Sheet5E602498/AMP_OUT: U4.14 (SENSE), U4.15 (OUT), U7.2 (+IN)
/Sheet5E602498/BOOST_EN: U5.4 (EN); also elsewhere on the board
/Sheet5E602498/CLK_nRF: U4.8 (CLK), U7.7 (DCLOCK); also elsewhere on the board
/Sheet5E602498/CS1_nRF: U4.6 (CS); also elsewhere on the board
/Sheet5E602498/CS2_nRF: U7.5 (~CS/SHDN); also elsewhere on the board
/Sheet5E602498/EN_nRF: U8.3 (EN); also elsewhere on the board
/Sheet5E602498/IN+: J3.1, U4.2 (IN+)
/Sheet5E602498/IN-: J3.2, U4.3 (IN-)
/Sheet5E602498/MISO_nRF: U7.6 (DOUT); also elsewhere on the board
/Sheet5E602498/MOSI_nRF: U4.7 (DIN); also elsewhere on the board
/Sheet5E602498/SHDW_nRF: U4.1 (SHDN); also elsewhere on the board
/Sheet5E602498/V5V: C23.1, C24.1, C25.1, C31.1, J3.4, R8.2, U4.16 (V+), U6.5 (VOUT), U7.8 (+VCC), U8.2 (VIN)
/Sheet5E602498/VBAT: C22.1, C26.1, L4.1, U5.5 (VIN); also elsewhere on the board
/Sheet5E602498/VBOOST: C27.1, C28.1, C29.1, D5.1 (K), R7.1, U6.1 (VIN)
/Sheet5E602498/Vlc: R8.1, R9.1, U4.13 (REF), U7.3 (-IN); also elsewhere on the board
GND: C22.2, C23.2, C24.2, C25.2, C26.2, C28.2, C29.2, C30.2, C31.2, J3.3, R6.2, R9.2, U4.4 (V-), U4.10 (DGND), U4.11 (PRLL_SRL), U5.2 (GND), U6.2 (GND), U7.4 (GND), U8.1 (GND_3), U8.4 (GND_4), U8.7 (GND_2), U8.8 (GND); also elsewhere on the board
unnamed: C27.2, R6.1, R7.2, U5.3 (FB)
unnamed: C30.1, U6.4 (BP)
unnamed: D5.2 (A), L4.2, U5.1 (SHDW)

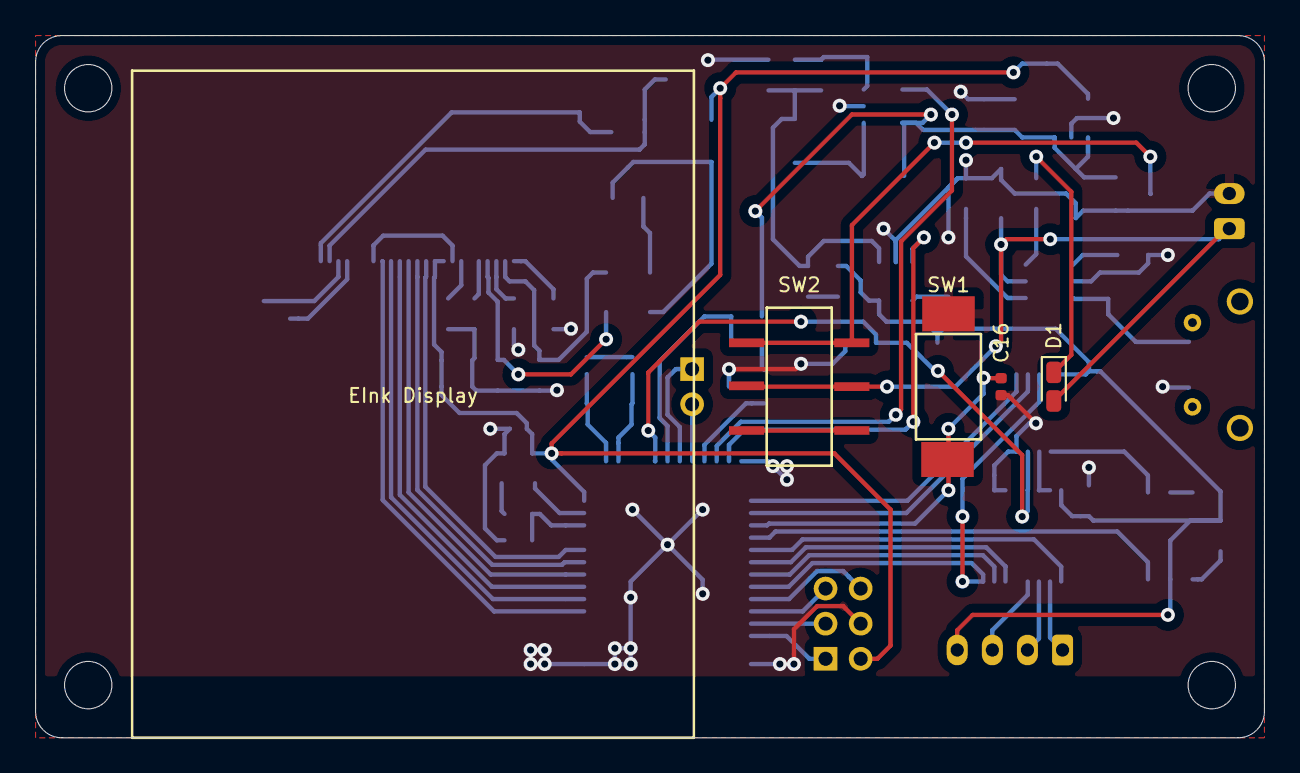
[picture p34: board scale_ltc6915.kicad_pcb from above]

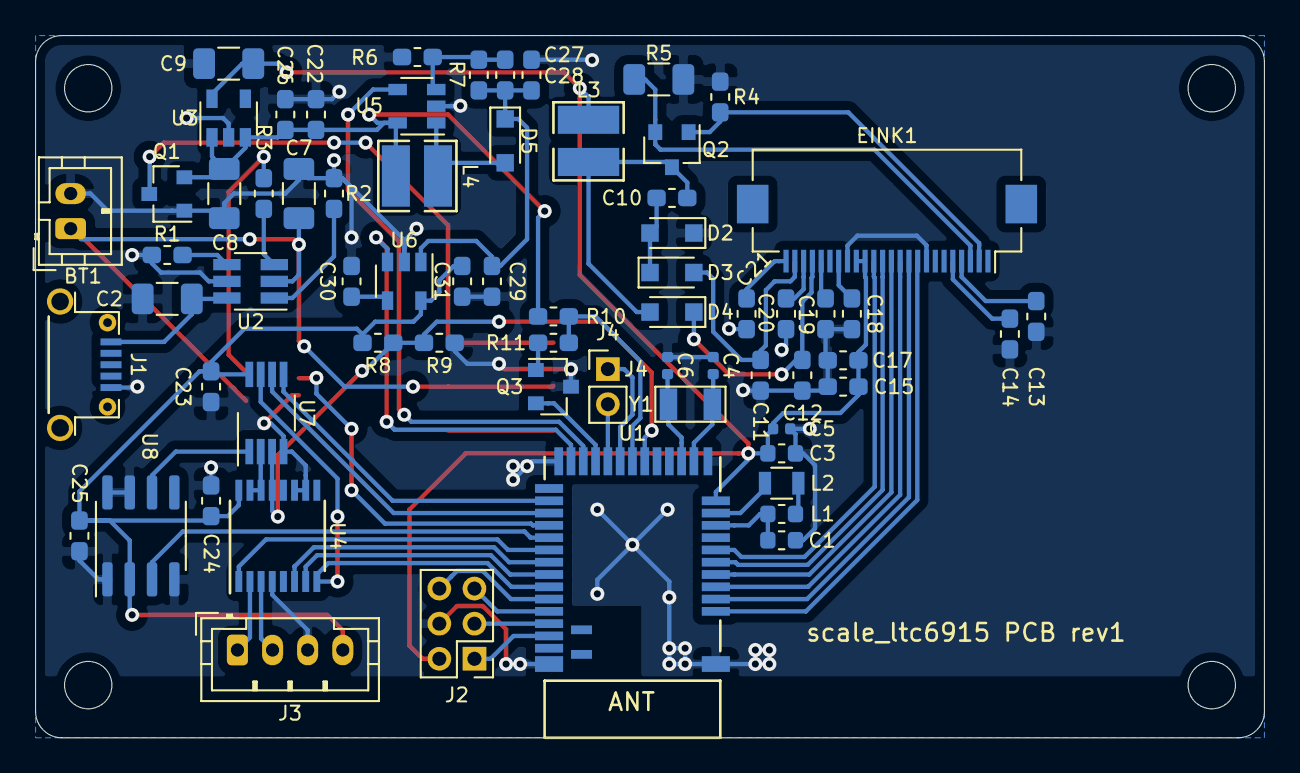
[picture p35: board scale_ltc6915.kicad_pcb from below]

Board: 2 copper layers, 70.0 x 40.0 mm, 76 parts (67 on the bottom side), 62 nets.

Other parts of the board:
EInk Display: 1.54inch_EInk_display

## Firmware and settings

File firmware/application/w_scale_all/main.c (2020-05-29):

/*
 *  main.c : Application to test display library
 *  Copyright (C) 2020  Appiko
 *
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
 *  You should have received a copy of the GNU General Public License
 *  along with this program.  If not, see <https://www.gnu.org/licenses/>.
 */

/**
 * @addtogroup group_appln
 * @{
 *
 *
 * @{
 *
 */

#include <stdbool.h>
#include <stdint.h>
#include <stddef.h>
#include <string.h>

#include "boards.h"
#include "hal_nop_delay.h"
#include "weighing_scale_ble.h"
#include "weight_mod.h"
#include "log.h"
#include "nrf_sdm.h"
#include "nrf_nvic.h"
#include "ms_timer.h"
#include "nrf_util.h"
#include "hal_gpio.h"

#define BUTTON_GPIOTE_CH 0

#define BUTTON_USED BUTTON_PIN

w_scale_ble_sw_ver_t sw_vers =
{
    .sw_ver = "0.1.0",
};

bool g_is_ble_connected = false;

void button_handler ();

void GPIOTE_IRQHandler (void)
{
    if (NRF_GPIOTE->EVENTS_IN[BUTTON_GPIOTE_CH])
    {
        NRF_GPIOTE->INTENCLR = (1 << BUTTON_GPIOTE_CH);
        NRF_GPIOTE->EVENTS_IN[BUTTON_GPIOTE_CH] = 0;
        button_handler ();
        NRF_GPIOTE->INTENSET = (1 << BUTTON_GPIOTE_CH);
    }

}

void reset_and_ota ()
{
    NRF_POWER->GPREGRET = 0xB1;
    uint8_t is_sd_enabled;
    sd_softdevice_is_enabled(&is_sd_enabled);
    if(is_sd_enabled == 0)
    {
        sd_nvic_SystemReset();
    }
    else
    {
        NVIC_SystemReset ();
    }
}

void connection_status (bool new_status)
{
    g_is_ble_connected = new_status;
}

void OTA_flag_update (w_scale_ble_force_ota_t ota)
{
    if (ota)
    {
        reset_and_ota ();
    }
}

void tare_set_zero (w_scale_ble_tare_to_zero_t set_zero)
{
    weight_mod_set_tare (set_zero);
}

void app_process ()
{
    if(g_is_ble_connected)
    {
        w_scale_ble_update_weight ((w_scale_ble_weight_t) weight_mod_get_wt ());
        w_scale_ble_update_batt_percent ((w_scale_ble_batt_percent_t) weight_mod_get_batt_percent ());
    }
    else
    {
        w_scale_ble_update_adv ((w_scale_ble_weight_t) weight_mod_get_wt ());
    }
}

weight_mod_hw_t dev_config = 
{
    .disp_hw.busy_pin = EINK_BUSY,
    .disp_hw.rst_pin = EINK_RST,
    .disp_hw.dc_pin = EINK_DC,
    .disp_hw.cs_pin = EINK_CS,
    .disp_hw.clk_pin = EINK_SCLK,
    .disp_hw.din_pin = EINK_MOSI,
    .disp_hw.dout_pin = EINK_MISO,
    
    .batt_hw.batt_lv = BT_LV,
    .batt_hw.batt_lv_en = BT_LV_EN,
    .batt_hw.batt_chrg_status = GPIO_0,
    
    .wt_scale_hw.pwr_boost_en = BOOST_EN,
    .wt_scale_hw.pwr_ldo_en = LDO_EN,
    .wt_scale_hw.pwr_vlc = VLC_PIN,

#ifdef HX_ADC
    .wt_scale_hw.hx_clk = HX711_CLK,
    .wt_scale_hw.hx_data = HX711_DATA,
    .wt_scale_hw.hx_rate = HX711_RATE,
#elif defined LTC_ADC
    .wt_scale_hw.common_clk = AMP_ADC_CLK,
    .wt_scale_hw.miso = AMP_ADC_MISO,
    .wt_scale_hw.mosi = AMP_ADC_MOSI,
    .wt_scale_hw.CS_amp = LTC6915_AMP_CS,
    .wt_scale_hw.CS_adc = ADS8320_ADC_CS,
    .wt_scale_hw.SHDN_amp = LTC6915_SHDN,
    .wt_scale_hw.EN_ref = LM4140_REF_EN,
#endif

    .callback = app_process,
};

void leds_init ()
{
    
}

void button_handler ()
{
    log_printf("%s\n", __func__);
    weight_mod_set_tare (true);
}

void button_init (app_irq_priority_t irq_priority)
{
    hal_gpio_cfg_input (BUTTON_USED, HAL_GPIO_PULL_UP);
    NRF_GPIOTE->CONFIG[BUTTON_GPIOTE_CH] = 
        (GPIOTE_CONFIG_MODE_Event << GPIOTE_CONFIG_MODE_Pos|
        ((BUTTON_USED << GPIOTE_CONFIG_PSEL_Pos) & GPIOTE_CONFIG_PSEL_Msk));
    
    if (BUTTONS_ACTIVE_STATE)
    {
        NRF_GPIOTE->CONFIG[BUTTON_GPIOTE_CH] |= 
            GPIOTE_CONFIG_POLARITY_LoToHi << GPIOTE_CONFIG_POLARITY_Pos; 
    }
    else
    {
        NRF_GPIOTE->CONFIG[BUTTON_GPIOTE_CH] |= 
            GPIOTE_CONFIG_POLARITY_HiToLo << GPIOTE_CONFIG_POLARITY_Pos; 
    }

    NRF_GPIOTE->INTENSET = (1 << BUTTON_GPIOTE_CH);

    NVIC_ClearPendingIRQ(GPIOTE_IRQn);
    NVIC_SetPriority(GPIOTE_IRQn, irq_priority);
    NVIC_EnableIRQ(GPIOTE_IRQn);
}

void boot_pwr_config(void)
{
//Enable the DCDC converter if the board supports it
#if DC_DC_CIRCUITRY == true  //Defined in the board header file
    NRF_POWER->DCDCEN = POWER_DCDCEN_DCDCEN_Enabled << POWER_DCDCEN_DCDCEN_Pos;
#endif
    NRF_POWER->TASKS_LOWPWR = 1;
}

int main(void)
{
    log_printf("Hello World from RTT\n");
    lfclk_init (BOARD_LFCLKSRC);
    boot_pwr_config();
    ms_timer_init (APP_IRQ_PRIORITY_LOWEST);
    
    w_scale_ble_init (OTA_flag_update,tare_set_zero,connection_status);
    w_scale_ble_set_sw_ver(&sw_vers);
    button_init (APP_IRQ_PRIORITY_LOW);
    weight_mod_init (&dev_config);
    leds_init ();
    while (true)
    {
        __WFI();
    }
}

/** @} */
/** @} */

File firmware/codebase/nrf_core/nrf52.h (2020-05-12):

/****************************************************************************************************//**
 * @file     nrf52.h
 *
 * @brief    CMSIS Cortex-M4 Peripheral Access Layer Header File for
 *           nrf52 from Nordic Semiconductor.
 *
 * @version  V1
 * @date     14. December 2017
 *
 * @note     Generated with SVDConv V2.81d 
 *           from CMSIS SVD File 'nrf52.svd' Version 1,
 *
 * @par      Copyright (c) 2010 - 2017, Nordic Semiconductor ASA All rights reserved.
 *           
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
 *           2. Redistributions in binary form must reproduce the above copyright
 *           notice, this list of conditions and the following disclaimer in the
 *           documentation and/or other materials provided with the distribution.
 *           
 *           3. Neither the name of Nordic Semiconductor ASA nor the names of its
 *           contributors may be used to endorse or promote products derived from this
 *           software without specific prior written permission.
 *           
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
 *
 *******************************************************************************************************/



/** @addtogroup Nordic Semiconductor
  * @{
  */

/** @addtogroup nrf52
  * @{
  */

#ifndef NRF52_H
#define NRF52_H

#ifdef __cplusplus
extern "C" {
#endif


/* -------------------------  Interrupt Number Definition  ------------------------ */

typedef enum {
/* -------------------  Cortex-M4 Processor Exceptions Numbers  ------------------- */
  Reset_IRQn                    = -15,              /*!<   1  Reset Vector, invoked on Power up and warm reset                 */
  NonMaskableInt_IRQn           = -14,              /*!<   2  Non maskable Interrupt, cannot be stopped or preempted           */
  HardFault_IRQn                = -13,              /*!<   3  Hard Fault, all classes of Fault                                 */
  MemoryManagement_IRQn         = -12,              /*!<   4  Memory Management, MPU mismatch, including Access Violation
                                                         and No Match                                                          */
  BusFault_IRQn                 = -11,              /*!<   5  Bus Fault, Pre-Fetch-, Memory Access Fault, other address/memory
                                                         related Fault                                                         */
  UsageFault_IRQn               = -10,              /*!<   6  Usage Fault, i.e. Undef Instruction, Illegal State Transition    */
  SVCall_IRQn                   =  -5,              /*!<  11  System Service Call via SVC instruction                          */
  DebugMonitor_IRQn             =  -4,              /*!<  12  Debug Monitor                                                    */
  PendSV_IRQn                   =  -2,              /*!<  14  Pendable request for system service                              */
  SysTick_IRQn                  =  -1,              /*!<  15  System Tick Timer                                                */
/* ----------------------  nrf52 Specific Interrupt Numbers  ---------------------- */
  POWER_CLOCK_IRQn              =   0,              /*!<   0  POWER_CLOCK                                                      */
  RADIO_IRQn                    =   1,              /*!<   1  RADIO                                                            */
  UARTE0_UART0_IRQn             =   2,              /*!<   2  UARTE0_UART0                                                     */
  SPIM0_SPIS0_TWIM0_TWIS0_SPI0_TWI0_IRQn=   3,      /*!<   3  SPIM0_SPIS0_TWIM0_TWIS0_SPI0_TWI0                                */
  SPIM1_SPIS1_TWIM1_TWIS1_SPI1_TWI1_IRQn=   4,      /*!<   4  SPIM1_SPIS1_TWIM1_TWIS1_SPI1_TWI1                                */
  NFCT_IRQn                     =   5,              /*!<   5  NFCT                                                             */
  GPIOTE_IRQn                   =   6,              /*!<   6  GPIOTE                                                           */
  SAADC_IRQn                    =   7,              /*!<   7  SAADC                                                            */
  TIMER0_IRQn                   =   8,              /*!<   8  TIMER0                                                           */
  TIMER1_IRQn                   =   9,              /*!<   9  TIMER1                                                           */
  TIMER2_IRQn                   =  10,              /*!<  10  TIMER2                                                           */
  RTC0_IRQn                     =  11,              /*!<  11  RTC0                                                             */
  TEMP_IRQn                     =  12,              /*!<  12  TEMP                                                             */
  RNG_IRQn                      =  13,              /*!<  13  RNG                                                              */
  ECB_IRQn                      =  14,              /*!<  14  ECB                                                              */
  CCM_AAR_IRQn                  =  15,              /*!<  15  CCM_AAR                                                          */
  WDT_IRQn                      =  16,              /*!<  16  WDT                                                              */
  RTC1_IRQn                     =  17,              /*!<  17  RTC1                                                             */
  QDEC_IRQn                     =  18,              /*!<  18  QDEC                                                             */
  COMP_LPCOMP_IRQn              =  19,              /*!<  19  COMP_LPCOMP                                                      */
  SWI0_EGU0_IRQn                =  20,              /*!<  20  SWI0_EGU0                                                        */
  SWI1_EGU1_IRQn                =  21,              /*!<  21  SWI1_EGU1                                                        */
  SWI2_EGU2_IRQn                =  22,              /*!<  22  SWI2_EGU2                                                        */
  SWI3_EGU3_IRQn                =  23,              /*!<  23  SWI3_EGU3                                                        */
  SWI4_EGU4_IRQn                =  24,              /*!<  24  SWI4_EGU4                                                        */
  SWI5_EGU5_IRQn                =  25,              /*!<  25  SWI5_EGU5                                                        */
  TIMER3_IRQn                   =  26,              /*!<  26  TIMER3                                                           */
  TIMER4_IRQn                   =  27,              /*!<  27  TIMER4                                                           */
  PWM0_IRQn                     =  28,              /*!<  28  PWM0                                                             */
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

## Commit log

2020-03-06 initial commit, added design file(wip)
    [epaper.sch, loadcell.sch, nRF.sch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]
2020-03-06 Adds new footprints, and BoM.
    [epaper.sch, loadcell.sch, nRF.sch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]
2020-03-06 Schematics, BoM updated. New project added - scale_ltc6915
    [epaper.sch, loadcell.sch, nRF.sch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]
2020-03-06 First commit of TPS92515 driver, ready for manufacturing
    [tps92515_led_driver-B_Cu.gbl, tps92515_led_driver-B_Mask.gbs, tps92515_led_driver-B_SilkS.gbo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]
2020-03-06 Changes post gerber output in PCB file
    [tps92515_led_driver.kicad_pcb]
2020-03-07 PCB Files added, for scale_hx711
    [nRF.sch, scale_hx711.kicad_pcb, scale_hx711.sch]
2020-03-09 moved tps92515_led_driver to different repo
    [tps92515_led_driver-B_Cu.gbl, tps92515_led_driver-B_Mask.gbs, tps92515_led_driver-B_SilkS.gbo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]
2020-03-09 Adds extra GPIO pins for nrf in scale_hx711
    [nRF.sch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]
2020-03-09 updated schematic of scale_ltc6915, fixed issues
    [loadcell.sch, nRF.sch, scale_ltc6915.kicad_pcb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]
2020-03-10 BOMs, schematics updated, scale_ltc6915 PCB Design complete.
    [epaper.sch, loadcell.sch, nRF.sch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]
2020-03-10 DC, CS pins separated, issue fixed. In both scale_hx711 and scale_ltc6915.
    [epaper.sch, nRF.sch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]
2020-05-12 Add weighing scale board with hx711 in boards.h.
2020-05-21 Add board file for LTC6915 board
2020-05-21 Get the DFU hardware ID from board
2020-05-21 Change UUID from Batt ADC to batt percentage
2020-05-21 Update the Makefile for
    - Adding simple_adc.c for battery measurement
    - Add DFU board ID for generating the zip files
    - Remove GPIO as pin reset
2020-05-21 Few core changes
    - ms timer to start weighing is moved to weighing module
    - Added the initialization for LTC board
    - Bluetooth now can reset the tare
    - Added field for sw version
    [main.c]
2020-05-21 BLE part has few changes like
    - Weight is sent in adv now instead of scan response
    - Weight is in int32_t format in both characteristic and adv
    - Added the controller value and sw version value in the characteristic
    - Battery percent is characteristic instead of ADC
    - Sw version is in string format now
2020-05-21 GPIO 21 isn't pin reset by default
2020-05-21 HX711 board now works with external display temporarily
2020-05-21 Weight module major changes
    - Battery value can be got in mV and percentage
    - Weight would be got in int32_t in terms of grams
    - Tare can be reset now
    - MS timer is used in weighing module now to start the initialization and measurement
    - Added proper init struct for LTC board
    - Callback from this module when weighing is done
    - For HX711 the ADC value to grams conversion is added
    - Corrected HX711 sampling algo
    - Added battery measurement with ADC
    [weight_mod.c]
2020-05-22 Update Info display to:
    1. Display under 1kg weight in 0.xx format.
    2. Display negative weight properly.
2020-05-29 Add DCDC enable and switching to Low Pwr on boot
2020-05-29 Add LTC driver changes
2020-05-29 Correct definintion for CLK_SRC in the board file
    [weighing_scale_hx711.h]
2021-03-01 Adds schematic and pcb images.

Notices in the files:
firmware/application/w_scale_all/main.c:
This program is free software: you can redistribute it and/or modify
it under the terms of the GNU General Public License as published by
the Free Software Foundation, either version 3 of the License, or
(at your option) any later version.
